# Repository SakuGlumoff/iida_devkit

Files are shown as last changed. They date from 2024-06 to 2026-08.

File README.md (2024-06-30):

# Iida devkit

PCB design exercise

## Hardware

Hardware design related files can be found in the `hardware` directory.
To get started with hardware development, take a look at the _README_ file therein.

The harware was designed with [KiCad EDA](https://www.kicad.org/) and manufactured with [Aisler](https://aisler.net/).

## Firmware

Firmware source files can be found in the `firmware` directory.
To get started with firmware development, take a look at the _README_ file therein.

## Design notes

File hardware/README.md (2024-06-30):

# Hardware

Hardware for Iida devkit.

## Requirements

| Tool  | Version |
|---|---|
| KiCad | >= 8 |
| Git | >= 2.34 |

## How to get started

Install the required version of _KiCad_ from https://www.kicad.org/download/.
Install the required version of _Git_ from https://git-scm.com/downloads.
Download the symbol and part libraries used in this project by running `git submodule update --init --recursive`.
You can now open the project file `iida_devkit.kicad_pro` with _KiCad_.

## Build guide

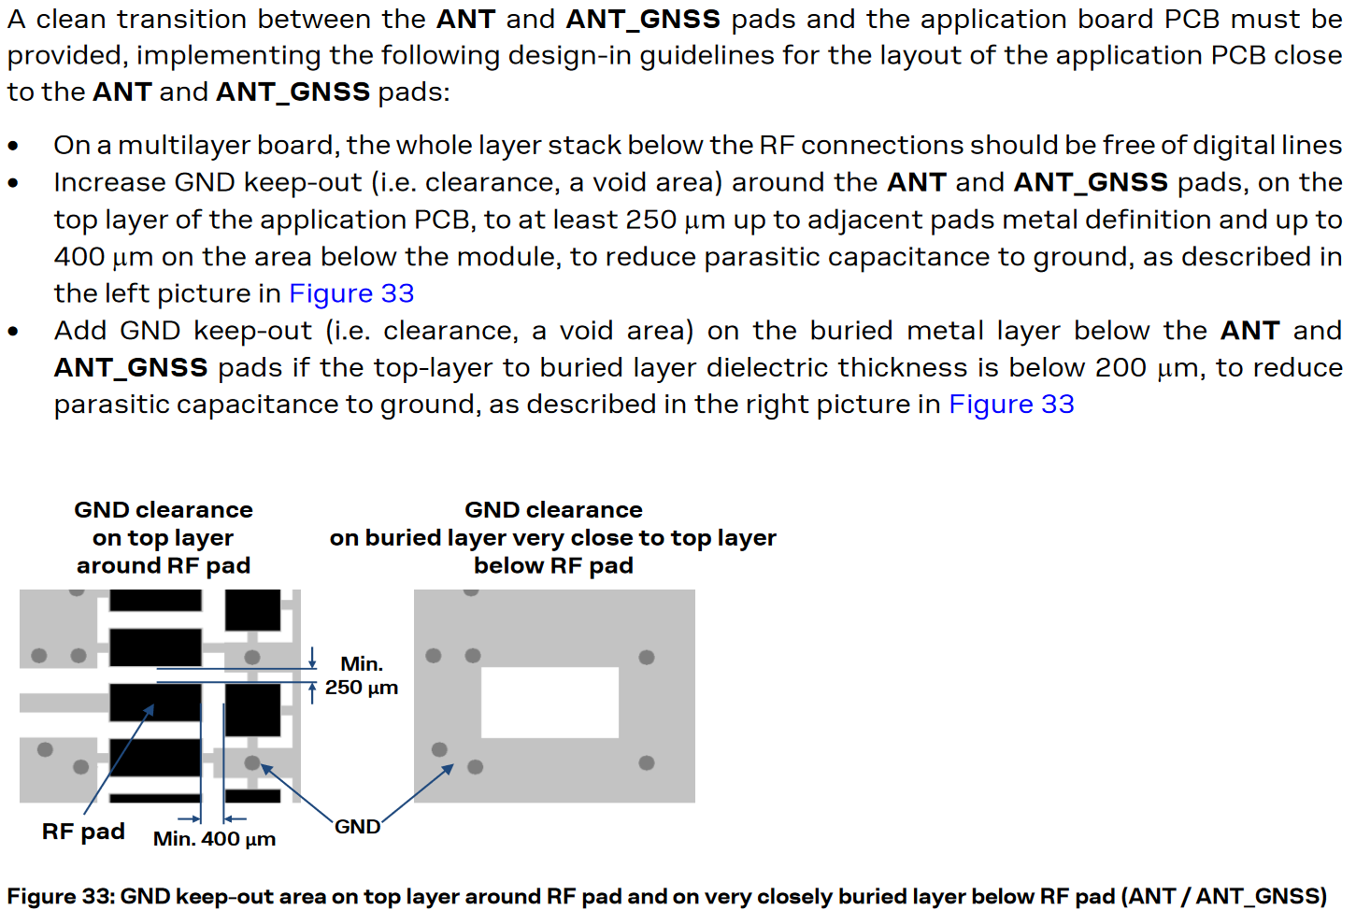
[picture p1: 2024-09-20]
hardware/img/sara-r5-sysintegrmanual-ant-pin.png

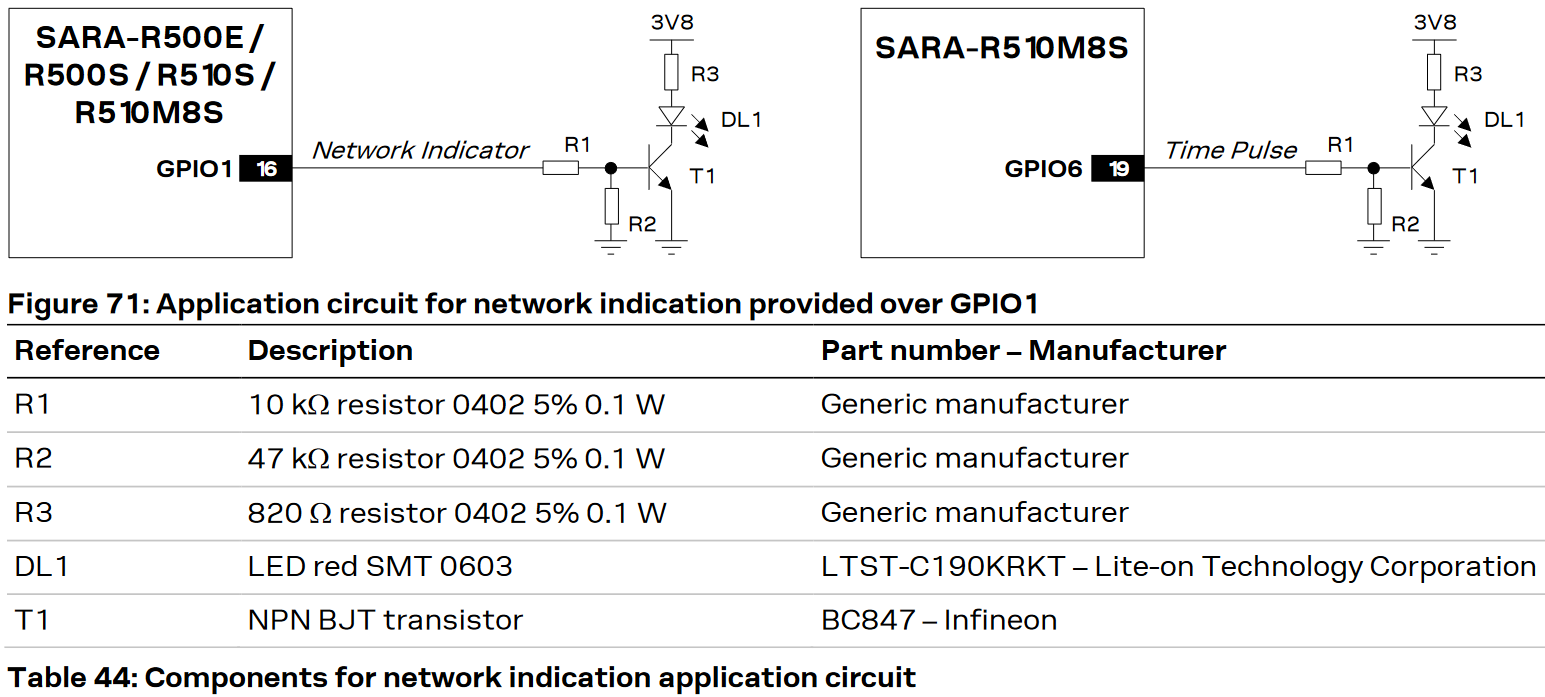
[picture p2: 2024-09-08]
hardware/img/sara-r5-sysintegrmanual-net-ind.png

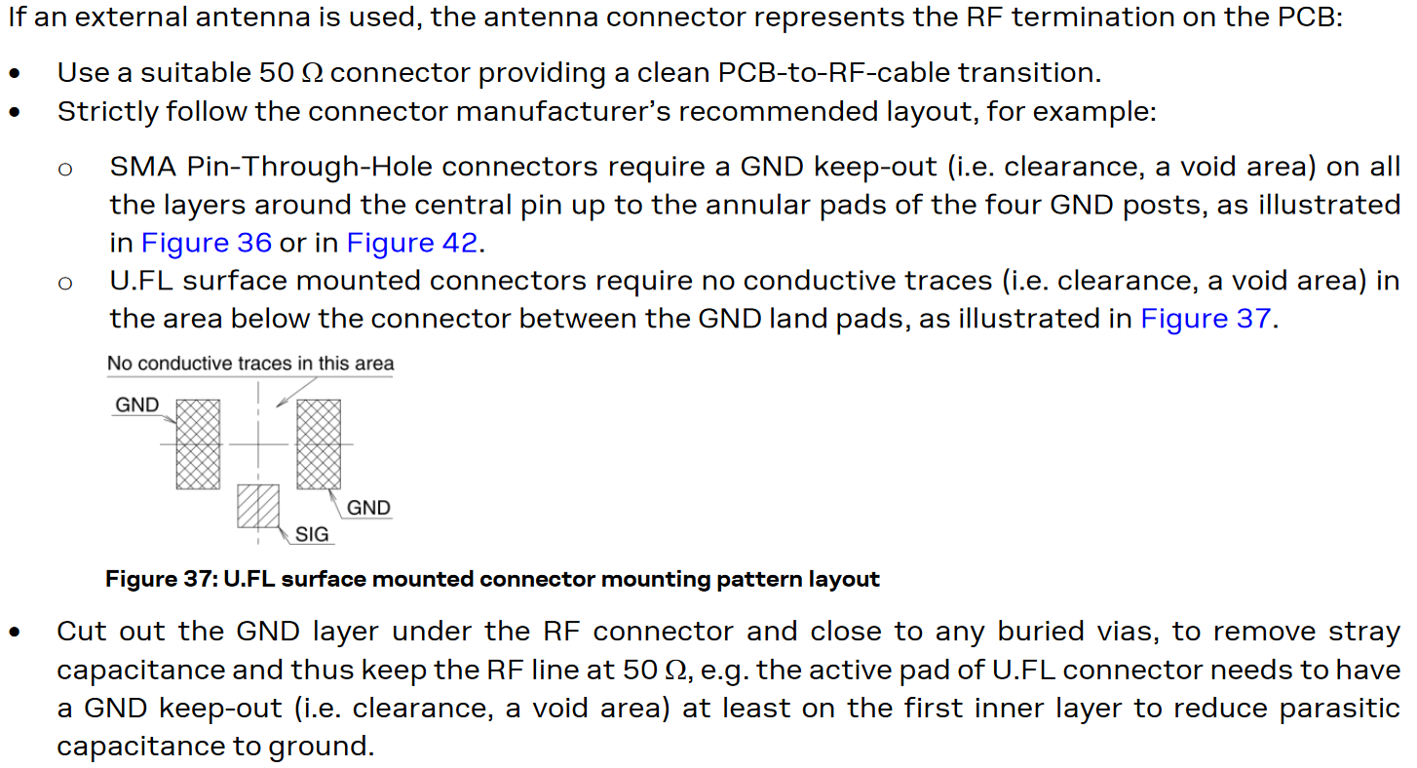
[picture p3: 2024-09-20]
hardware/img/sara-r5-sysintegrmanual-ant-ext.png

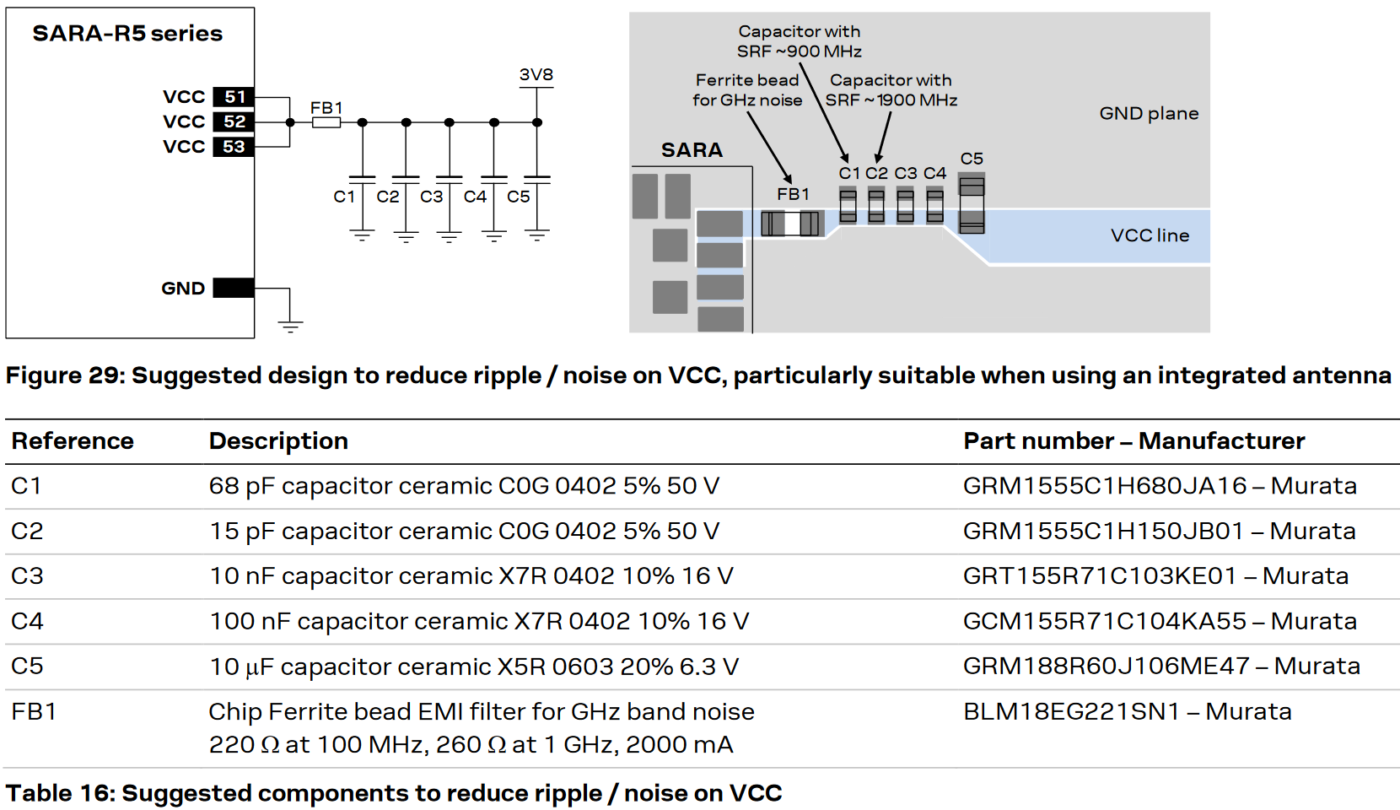
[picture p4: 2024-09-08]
hardware/img/sara-r5-sysintegrmanual-vcc.png

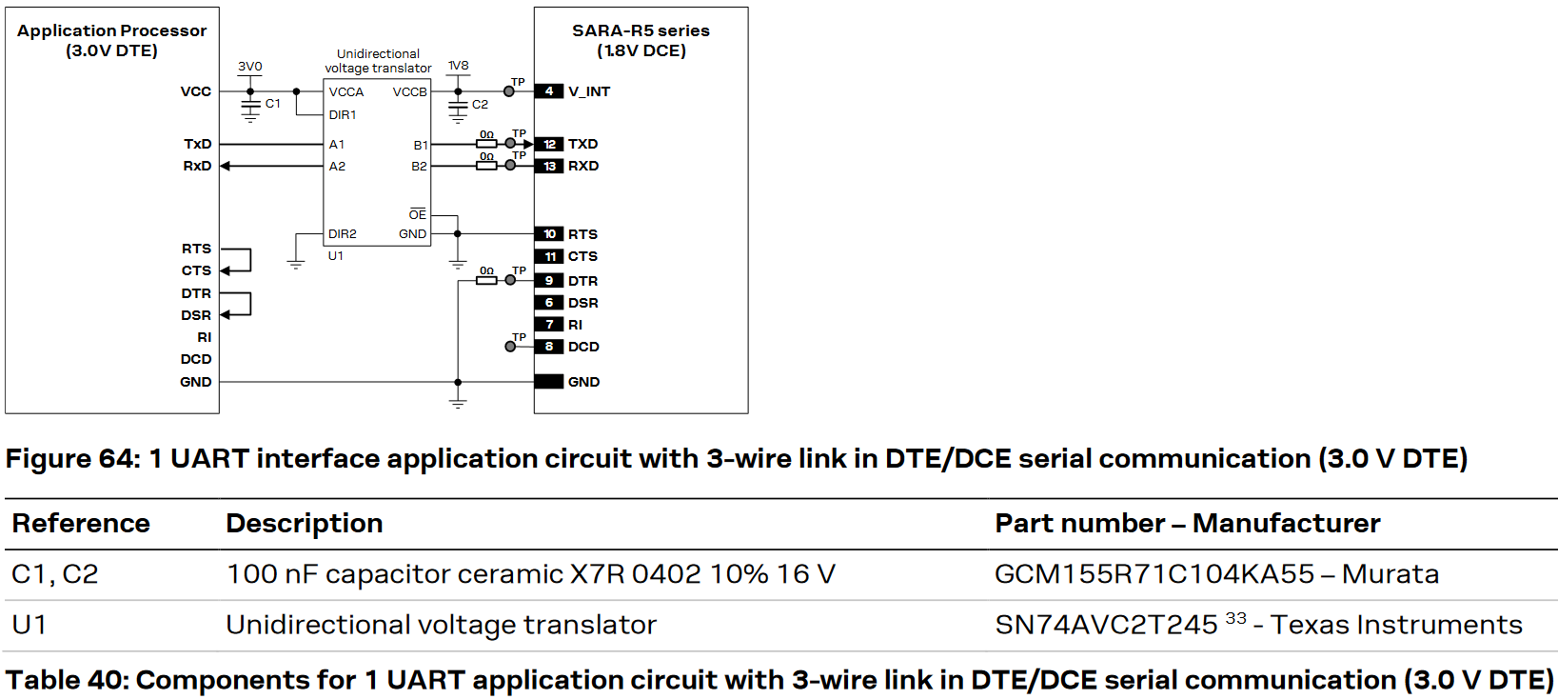
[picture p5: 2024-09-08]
hardware/img/sara-r5-sysintegrmanual-uart.png

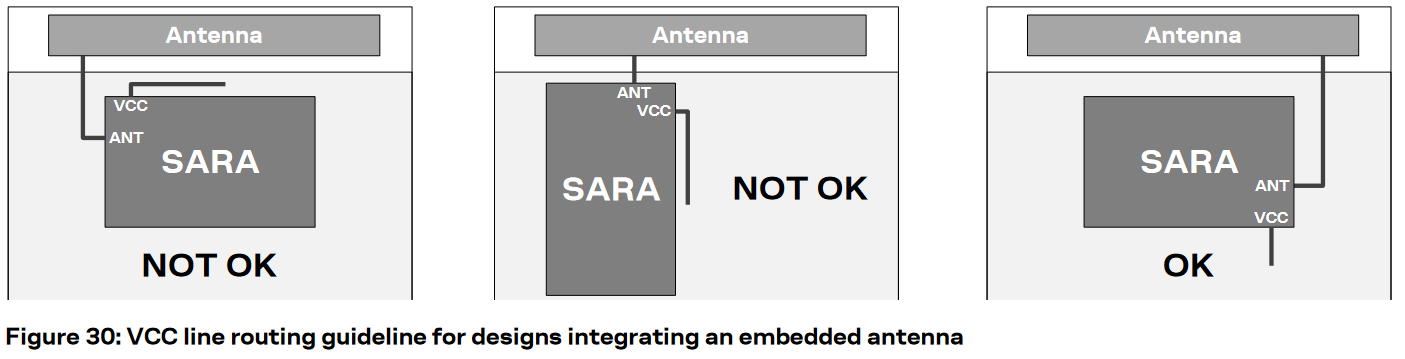
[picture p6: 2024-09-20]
hardware/img/sara-r5-sysintegrmanual-vcc-ant.png

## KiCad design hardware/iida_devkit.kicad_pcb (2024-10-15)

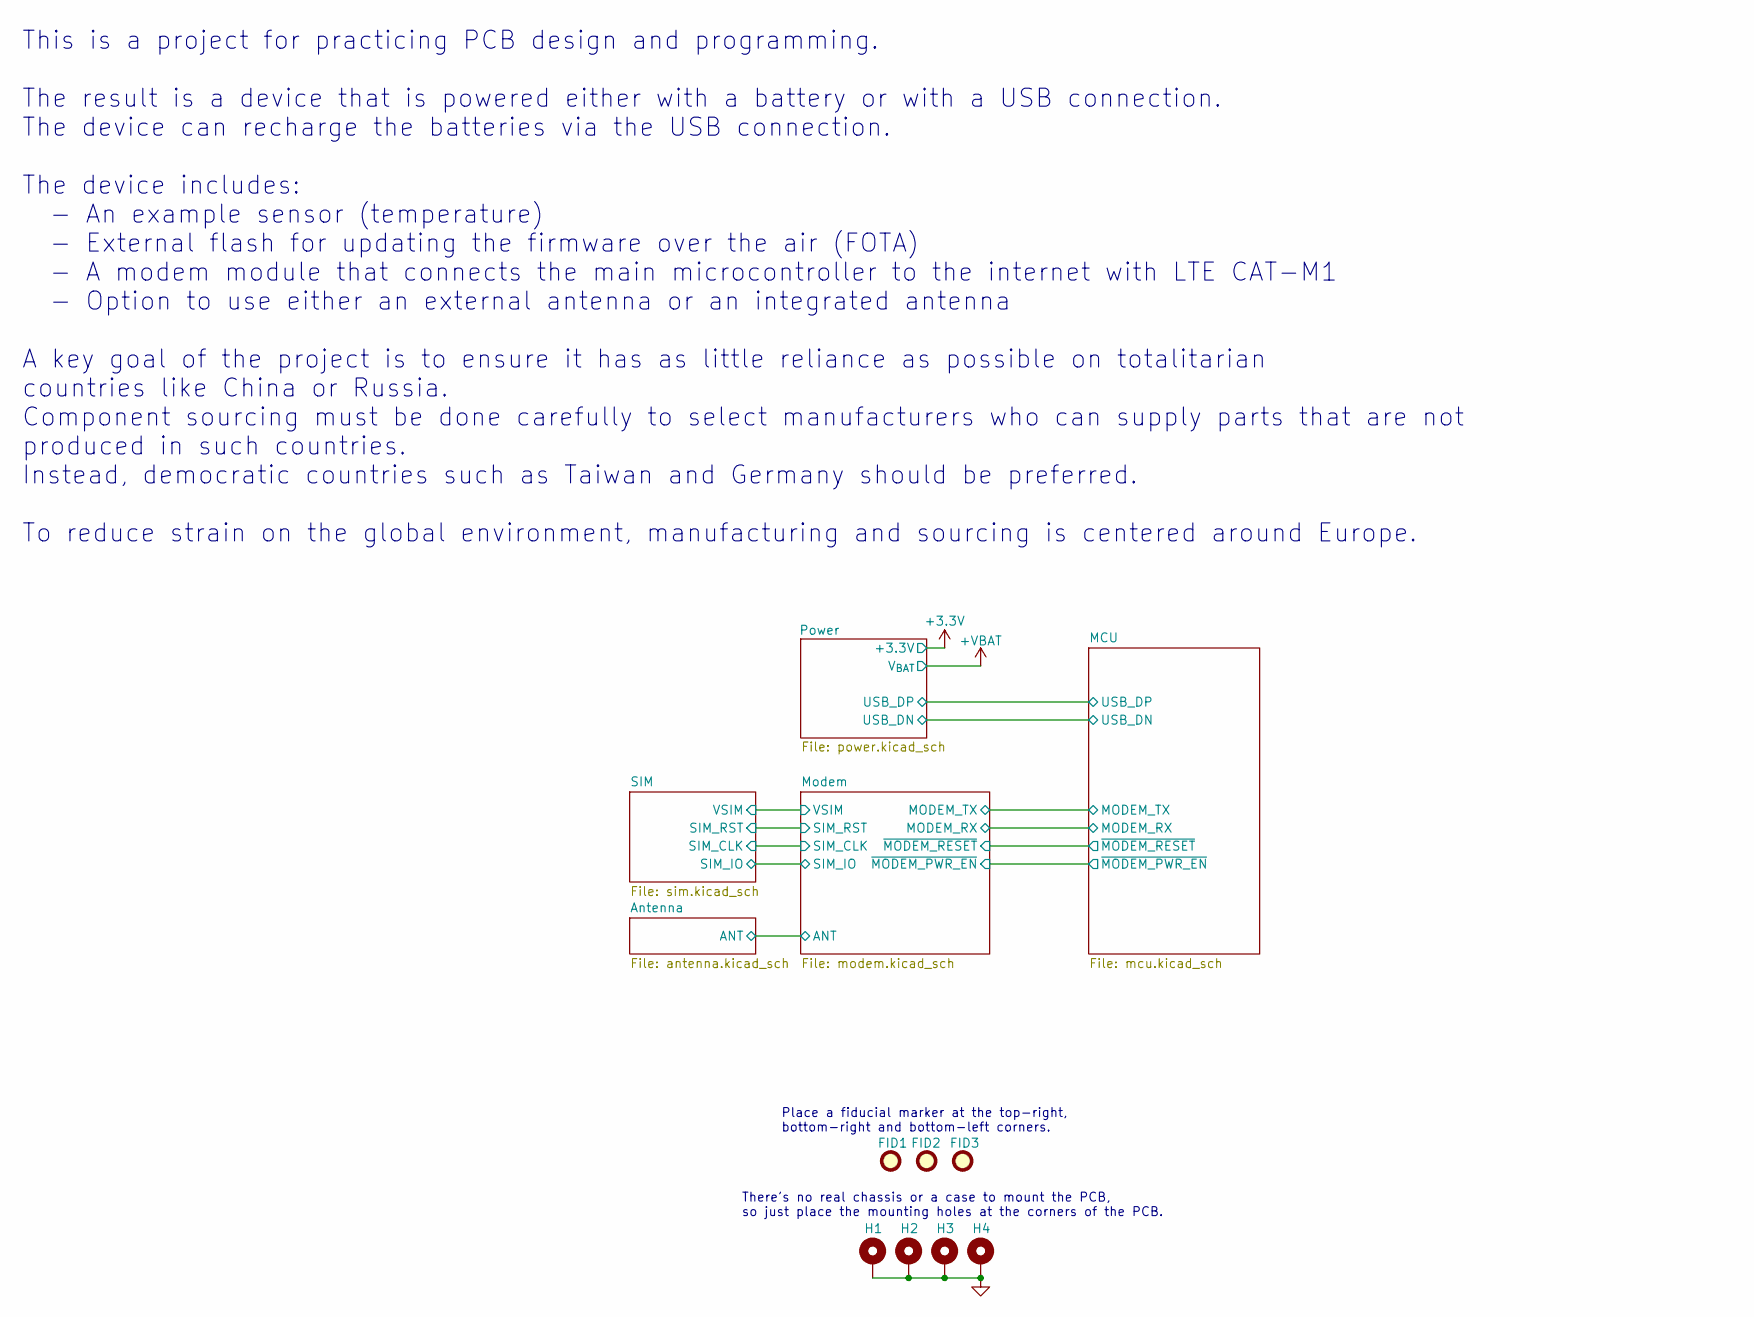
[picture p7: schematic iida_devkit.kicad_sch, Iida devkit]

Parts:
FID1, FID2, FID3: Fiducial; Fiducial_1mm_Mask2mm
H1, H2, H3, H4: MountingHole_Pad; MountingHole_2.2mm_M2_Pad_Via

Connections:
GND: H1.1, H2.1, H3.1, H4.1; also elsewhere on the board

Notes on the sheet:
There's no real chassis or a case to mount the PCB, so just place the mounting holes at the corners of the PCB.
Place a fiducial marker at the top-right, bottom-right and bottom-left corners.
This is a project for practicing PCB design and programming. The result is a device that is powered either with a battery or with a USB connection. The device can recharge the batteries via the USB connection. The device includes: - An example sensor (temperature) - External flash for updating the 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

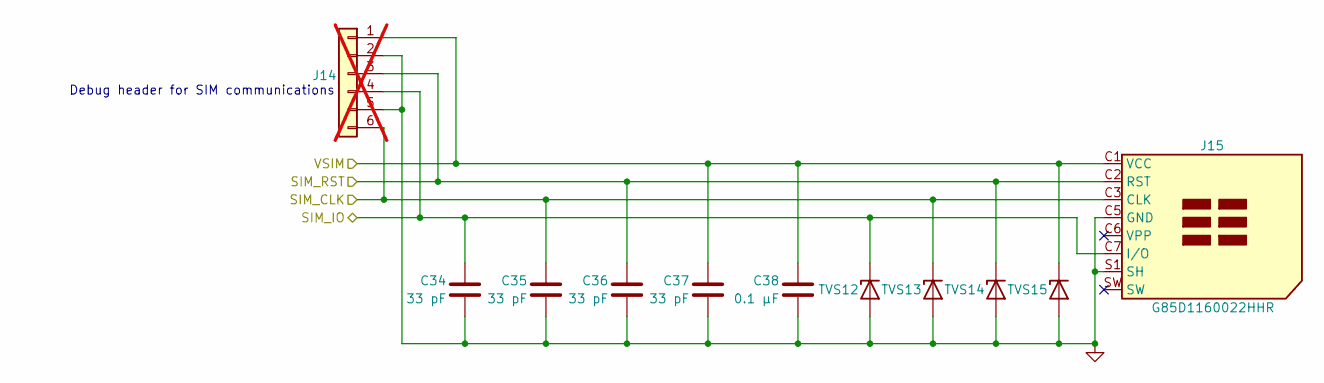
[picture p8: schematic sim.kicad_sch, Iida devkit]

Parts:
C34, C35, C36, C37: 33 pF; C_0603_1608Metric_Pad1.08x0.95mm_HandSolder; Manufacturer Part Number 885012006005; Digi-Key Part Number 732-7749-1-ND
C38: 0.1 µF; C_0603_1608Metric_Pad1.08x0.95mm_HandSolder; Manufacturer Part Number 885012206071; Digi-Key Part Number 732-7989-1-ND
J14: PRPC006SAAN-RC; PinHeader_1x06_P2.54mm_Vertical; Manufacturer Part Number PRPC006SAAN-RC; Digi-Key Part Number S1011EC-06-ND; not fitted
J15: G85D1160022HHR; AMPHENOL_G85D1160022HHR; Manufacturer Part Number G85D1160022HHR; Digi-Key Part Number 664-G85D1160022HHRCT-ND
TVS12, TVS13, TVS14, TVS15: CPDUC5V0USP-HF; D_0603_1608Metric_Pad1.05x0.95mm_HandSolder; Manufacturer Part Number CPDUC5V0USP-HF; Digi-Key Part Number 641-1765-1-ND

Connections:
/Modem/SIM_CLK: C35.1, J14.6, J15.C3 (CLK), TVS13.1 (K); also elsewhere on the board
/Modem/SIM_IO: C34.1, J14.4, J15.C7 (I/O), TVS12.1 (K); also elsewhere on the board
/Modem/SIM_RST: C36.1, J14.3, J15.C2 (RST), TVS14.1 (K); also elsewhere on the board
/Modem/VSIM: C37.1, C38.1, J14.1, J15.C1 (VCC), TVS15.1 (K); also elsewhere on the board
GND: C34.2, C35.2, C36.2, C37.2, C38.2, J14.2, J14.5, J15.C5 (GND), J15.S1 (SH), J15.S2 (SH), J15.S3 (SH), TVS12.2 (A), TVS13.2 (A), TVS14.2 (A), TVS15.2 (A); also elsewhere on the board

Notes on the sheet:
Debug header for SIM communications

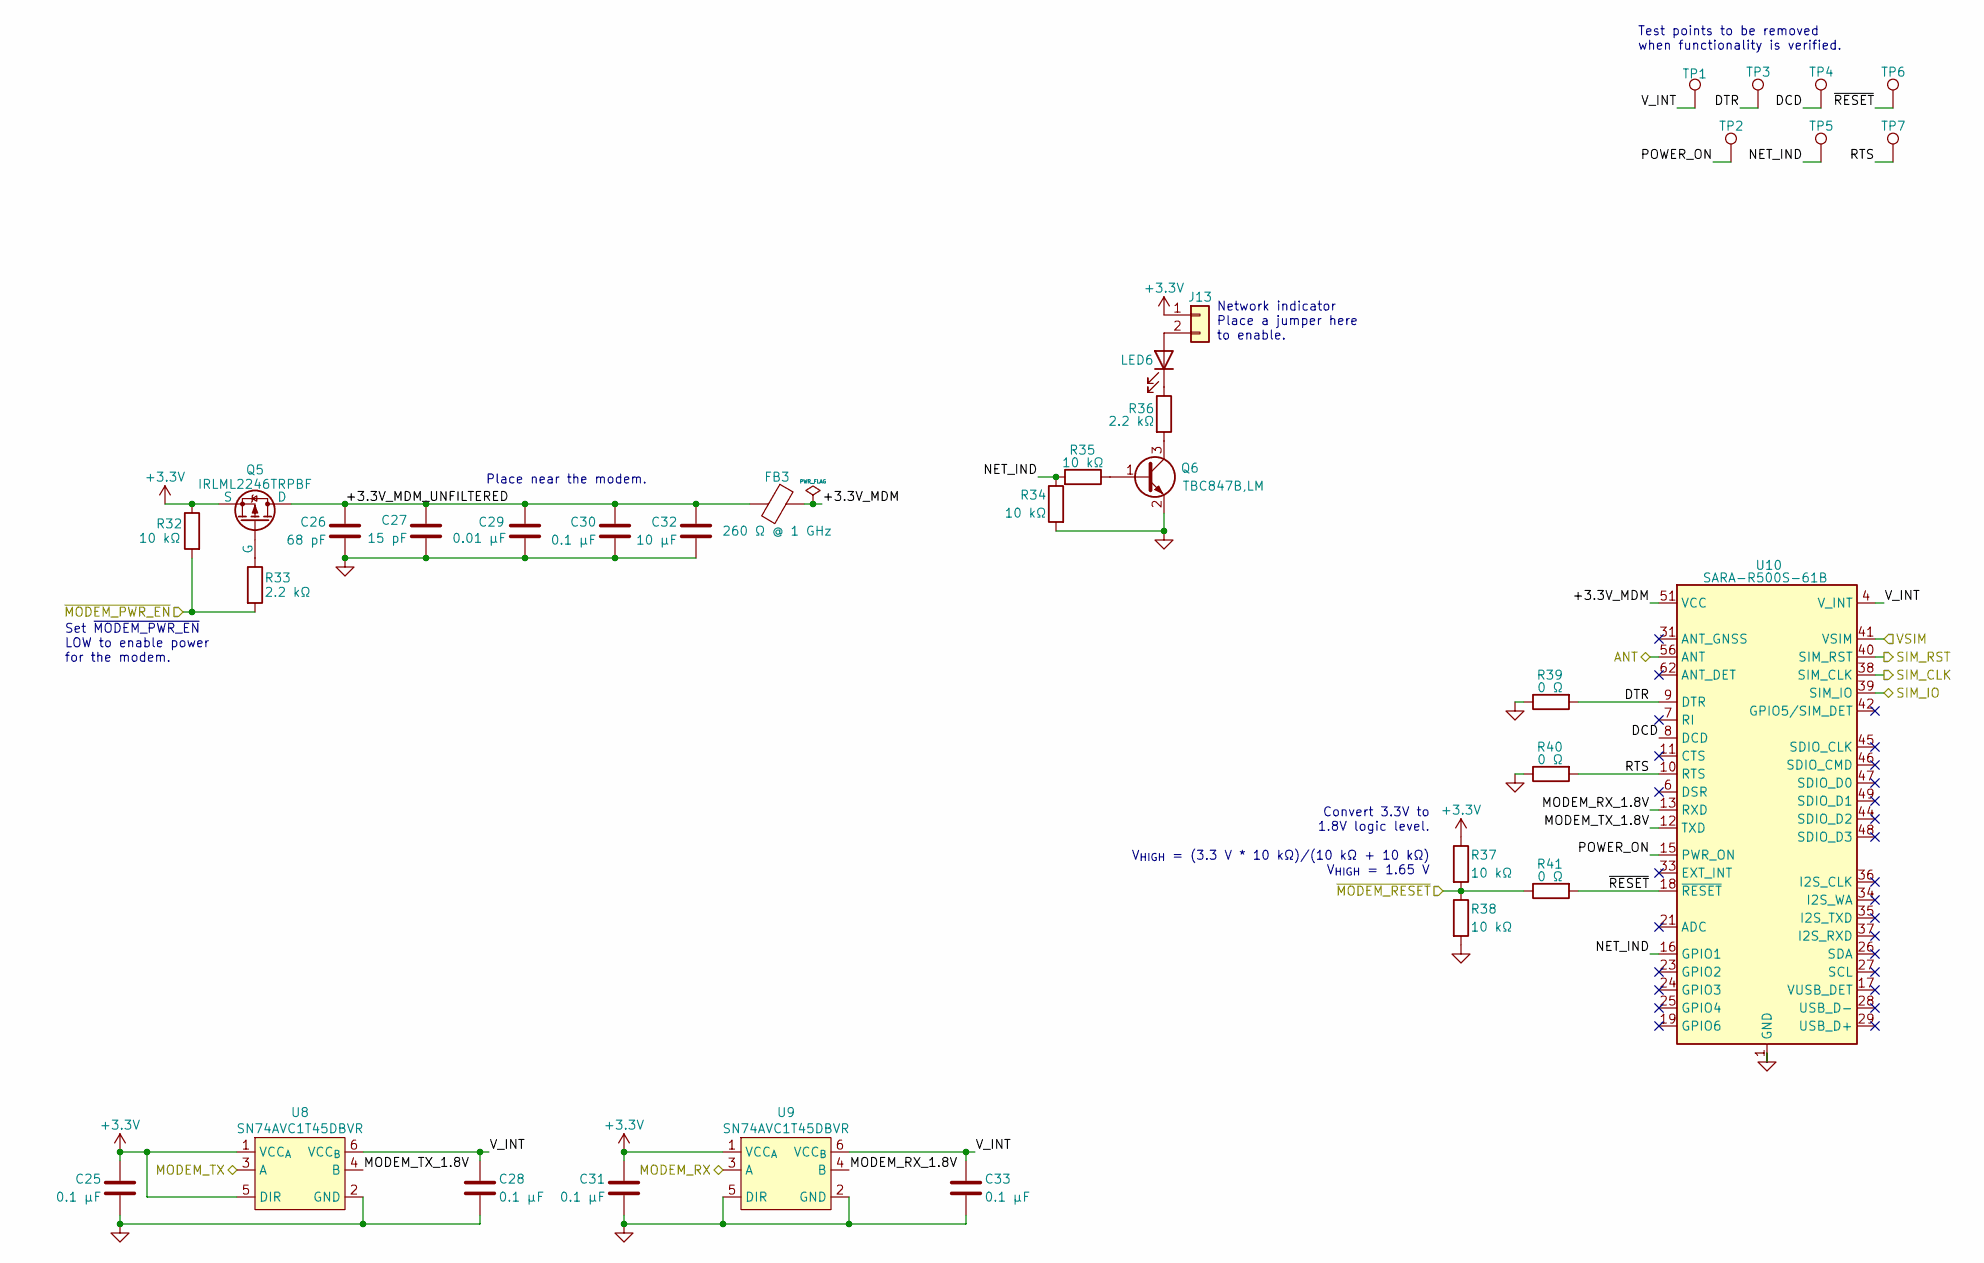
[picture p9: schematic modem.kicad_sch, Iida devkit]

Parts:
C25, C28, C30, C31, C33: 0.1 µF; C_0603_1608Metric_Pad1.08x0.95mm_HandSolder; Manufacturer Part Number 885012206071; Digi-Key Part Number 732-7989-1-ND
C26: 68 pF; C_0603_1608Metric_Pad1.08x0.95mm_HandSolder; Manufacturer Part Number 885012006037; Digi-Key Part Number 732-7779-1-ND
C27: 15 pF; C_0603_1608Metric_Pad1.08x0.95mm_HandSolder; Manufacturer Part Number 885012006003; Digi-Key Part Number 732-7747-1-ND
C29: 0.01 µF; C_0603_1608Metric_Pad1.08x0.95mm_HandSolder; Manufacturer Part Number 885012206089; Digi-Key Part Number 732-8007-1-ND
C32: 10 µF; C_0603_1608Metric_Pad1.08x0.95mm_HandSolder; Manufacturer Part Number 885012106006; Digi-Key Part Number 732-7903-1-ND
FB3: 260 Ω @ 1 GHz; R_0603_1608Metric_Pad0.98x0.95mm_HandSolder; Manufacturer Part Number BLM18EG221SN1D; Digi-Key Part Number 490-3992-1-ND
J13: PRPC001DAAN-RC; PinHeader_1x02_P2.54mm_Vertical; Manufacturer Part Number PRPC001DAAN-RC; Digi-Key Part Number S2011EC-01-ND
LED6: 150141YS73100; LED_PLCC_2835_Handsoldering; Manufacturer Part Number 150141YS73100; Digi-Key Part Number 732-5004-1-ND
Q5: IRLML2246TRPBF; SC-59_Handsoldering; Manufacturer Part Number IRLML2246TRPBF; Digi-Key Part Number IRLML2246TRPBFCT-ND
Q6: TBC847B,LM; SC-59_Handsoldering; Manufacturer Part Number TBC847B,LM; Digi-Key Part Number TBC847BLMCT-ND
R32, R34, R35, R37, R38: 10 kΩ; R_0603_1608Metric_Pad0.98x0.95mm_HandSolder; Manufacturer Part Number 560112116005; Digi-Key Part Number 732-560112116005CT-ND
R33, R36: 2.2 kΩ; R_0603_1608Metric_Pad0.98x0.95mm_HandSolder; Manufacturer Part Number 560112116098; Digi-Key Part Number 732-560112116098CT-ND
R39, R40, R41: 0 Ω; R_0805_2012Metric_Pad1.20x1.40mm_HandSolder; Manufacturer Part Number 560112120002; Digi-Key Part Number 732-560112120002CT-ND
TP1, TP2, TP3, TP4, TP5, TP6, TP7: TestPoint; TestPoint_Pad_D1.5mm
U8, U9: SN74AVC1T45DBVR; SOT-23-6_Handsoldering; Manufacturer Part Number SN74AVC1T45DBVR; Digi-Key Part Number 296-19094-1-ND
U10: SARA-R500S-61B; ublox_SARA_LGA-96; Manufacturer Part Number SARA-R500S-61B; Digi-Key Part Number 672-SARA-R500S-61BCT-ND

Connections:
+3.3V: C25.1, C31.1, J13.1, Q5.3 (S), R32.1, R37.1, U8.1 (VCC_{A}), U8.5 (DIR), U9.1 (VCC_{A}); also elsewhere on the board
/Antenna/ANT: U10.56 (ANT); also elsewhere on the board
/MCU/MODEM_RX: U9.3 (A); also elsewhere on the board
/MCU/MODEM_TX: U8.3 (A); also elsewhere on the board
/MCU/~MODEM_PWR_EN: R32.2, R33.2; also elsewhere on the board
/MCU/~MODEM_RESET: R37.2, R38.1, R41.1; also elsewhere on the board
/Modem/+3.3V_MDM: FB3.1, U10.51 (VCC), U10.52 (VCC), U10.53 (VCC)
/Modem/+3.3V_MDM_UNFILTERED: C26.1, C27.1, C29.1, C30.1, C32.1, FB3.2, Q5.1 (D)
/Modem/DCD: TP4.1, U10.8 (DCD)
/Modem/DTR: R39.2, TP3.1, U10.9 (DTR)
/Modem/MODEM_RX_1.8V: U9.4 (B), U10.13 (RXD)
/Modem/MODEM_TX_1.8V: U8.4 (B), U10.12 (TXD)
/Modem/NET_IND: R34.1, R35.2, TP5.1, U10.16 (GPIO1)
/Modem/POWER_ON: TP2.1, U10.15 (PWR_ON)
/Modem/RTS: R40.2, TP7.1, U10.10 (RTS)
/Modem/SIM_CLK: U10.38 (SIM_CLK); also elsewhere on the board
/Modem/SIM_IO: U10.39 (SIM_IO); also elsewhere on the board
/Modem/SIM_RST: U10.40 (SIM_RST); also elsewhere on the board
/Modem/VSIM: U10.41 (VSIM); also elsewhere on the board
/Modem/V_INT: C28.1, C33.1, TP1.1, U8.6 (VCC_{B}), U9.6 (VCC_{B}), U10.4 (V_INT)
/Modem/~RESET: R41.2, TP6.1, U10.18 (~RESET)
GND: C25.2, C26.2, C27.2, C28.2, C29.2, C30.2, C31.2, C32.2, C33.2, Q6.2 (E), R34.2, R38.2, R39.1, R40.1, U8.2 (GND), U9.2 (GND), U9.5 (DIR), U10.1 (GND), U10.3 (GND), U10.5 (GND), U10.14 (GND), U10.20 (GND), U10.22 (GND), U10.30 (GND), U10.32 (GND), U10.43 (GND), U10.50 (GND), U10.54 (GND), U10.55 (GND), U10.57 (GND), U10.58 (GND), U10.59 (GND), U10.60 (GND), U10.61 (GND), U10.63 (GND), U10.64 (GND), U10.65 (GND), U10.66 (GND), U10.67 (GND), U10.68 (GND), U10.69 (GND), U10.70 (GND), U10.71 (GND), U10.72 (GND), U10.73 (GND), U10.74 (GND), U10.75 (GND), U10.76 (GND), U10.77 (GND), U10.78 (GND), U10.79 (GND), U10.80 (GND), U10.81 (GND), U10.82 (GND), U10.83 (GND), U10.84 (GND), U10.85 (GND), U10.86 (GND), U10.87 (GND), U10.88 (GND), U10.89 (GND), U10.90 (GND), U10.91 (GND), U10.92 (GND), U10.93 (GND), U10.94 (GND), U10.95 (GND), U10.96 (GND); also elsewhere on the board
unnamed: J13.2, LED6.2 (A)
unnamed: LED6.1 (K), R36.1
unnamed: Q5.2 (G), R33.1
unnamed: Q6.1 (B), R35.1
unnamed: Q6.3 (C), R36.2

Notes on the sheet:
Convert 3.3V to 1.8V logic level. V_{HIGH} = (3.3 V * 10 kΩ)/(10 kΩ + 10 kΩ) V_{HIGH} = 1.65 V
Place near the modem.
Set ~{MODEM_PWR_EN} LOW to enable power for the modem.
Test points to be removed when functionality is verified.
Network indicator Place a jumper here to enable.

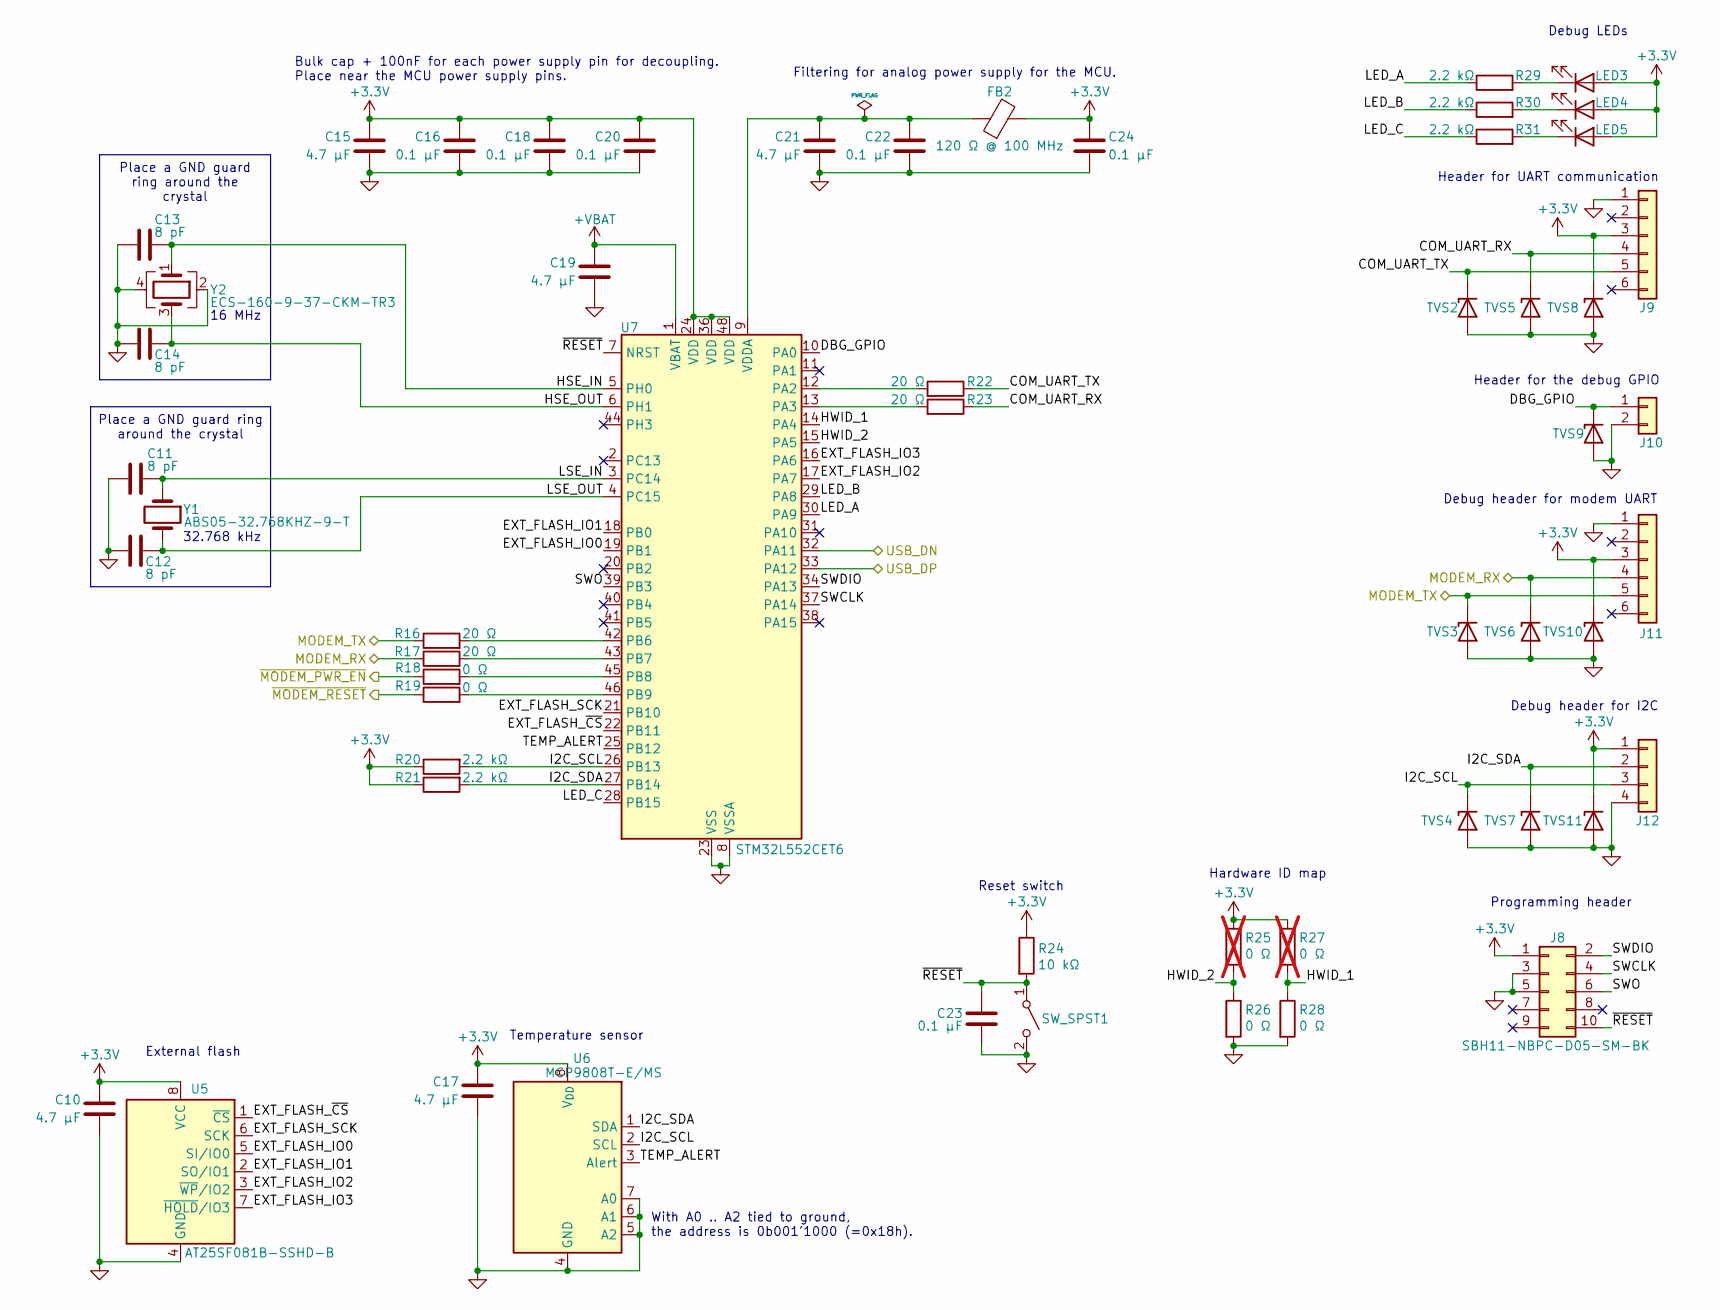
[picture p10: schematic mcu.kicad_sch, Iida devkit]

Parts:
C10, C15, C17, C19, C21: 4.7 µF; C_0805_2012Metric_Pad1.18x1.45mm_HandSolder; Manufacturer Part Number 885012107013; Digi-Key Part Number 732-7623-1-ND
C11, C12, C13, C14: 8 pF; C_0603_1608Metric_Pad1.08x0.95mm_HandSolder; Manufacturer Part Number 885012006093; Digi-Key Part Number 732-12050-1-ND
C16, C18, C20, C22, C23, C24: 0.1 µF; C_0603_1608Metric_Pad1.08x0.95mm_HandSolder; Manufacturer Part Number 885012206071; Digi-Key Part Number 732-7989-1-ND
FB2: 120 Ω @ 100 MHz; R_0603_1608Metric_Pad0.98x0.95mm_HandSolder; Manufacturer Part Number BLM18KG121TN1D; Digi-Key Part Number 490-5254-1-ND
J8: SBH11-NBPC-D05-SM-BK; IDC-Header_2x05_P2.54mm_Vertical_SMD; Manufacturer Part Number SBH11-NBPC-D05-SM-BK; Digi-Key Part Number S9185-ND
J9, J11: PRPC006SAAN-RC; PinHeader_1x06_P2.54mm_Vertical; Manufacturer Part Number PRPC006SAAN-RC; Digi-Key Part Number S1011EC-06-ND
J10: PRPC001DAAN-RC; PinHeader_1x02_P2.54mm_Vertical; Manufacturer Part Number PRPC001DAAN-RC; Digi-Key Part Number S2011EC-01-ND
J12: PRPC004SAAN-RC; PinHeader_1x04_P2.54mm_Vertical; Manufacturer Part Number PRPC004SAAN-RC; Digi-Key Part Number S1011EC-04-ND
LED3, LED4, LED5: 150141YS73100; LED_PLCC_2835_Handsoldering; Manufacturer Part Number 150141YS73100; Digi-Key Part Number 732-5004-1-ND
R16, R17, R22, R23: 20 Ω; R_0603_1608Metric_Pad0.98x0.95mm_HandSolder; Manufacturer Part Number 560112116125; Digi-Key Part Number 732-560112116125CT-ND
R18, R19, R26, R28: 0 Ω; R_0805_2012Metric_Pad1.20x1.40mm_HandSolder; Manufacturer Part Number 560112120002; Digi-Key Part Number 732-560112120002CT-ND
R20, R21, R29, R30, R31: 2.2 kΩ; R_0603_1608Metric_Pad0.98x0.95mm_HandSolder; Manufacturer Part Number 560112116098; Digi-Key Part Number 732-560112116098CT-ND
R24: 10 kΩ; R_0603_1608Metric_Pad0.98x0.95mm_HandSolder; Manufacturer Part Number 560112116005; Digi-Key Part Number 732-560112116005CT-ND
R25, R27: 0 Ω; R_0805_2012Metric_Pad1.20x1.40mm_HandSolder; Manufacturer Part Number 560112120002; Digi-Key Part Number 732-560112120002CT-ND; not fitted
SW_SPST1: 430182050816; SW_SPST_PTS645; Manufacturer Part Number 430182050816; Digi-Key Part Number 732-7005-1-ND
TVS2, TVS3, TVS4, TVS5, TVS6, TVS7, TVS8, TVS9, TVS10, TVS11: CPDUC5V0USP-HF; D_0603_1608Metric_Pad1.05x0.95mm_HandSolder; Manufacturer Part Number CPDUC5V0USP-HF; Digi-Key Part Number 641-1765-1-ND
U5: AT25SF081B-SSHD-B; SOIC-8_3.9x4.9mm_P1.27mm; Manufacturer Part Number AT25SF081B-SSHD-B; Digi-Key Part Number 1265-AT25SF081B-SSHD-B-ND
U6: MCP9808T-E/MS; MSOP-8_3x3mm_P0.65mm; Manufacturer Part Number MCP9808T-E/MS; Digi-Key Part Number MCP9808T-E/MSCT-ND
U7: STM32L552CET6; LQFP-48_7x7mm_P0.5mm; Manufacturer Part Number STM32L552CET6; Digi-Key Part Number 497-STM32L552CET6-ND
Y1: ABS05-32.768KHZ-9-T; Crystal_SMD_MicroCrystal_CM9V-T1A-2Pin_1.6x1.0mm_HandSolder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; Manufacturer Part Number ABS05-32.768KHZ-9-T; Digi-Key Part Number 535-ABS05-32.768KHZ-9-TCT-ND
Y2: ECS-160-9-37-CKM-TR3; Crystal_SMD_3225-4Pin_3.2x2.5mm_HandSoldering; Manufacturer Part Number ECS-160-9-33B-CKM-TR3; Digi-Key Part Number 50-ECS-160-9-33B-CKM-TR3CT-ND

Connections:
+3.3V: C10.1, C15.1, C16.1, C17.1, C18.1, C20.1, C24.1, FB2.2, J8.1, J9.3, J11.3, J12.1, LED3.2 (A), LED4.2 (A), LED5.2 (A), R20.1, R21.1, R24.1, R25.1, R27.1, TVS8.1 (K), TVS10.1 (K), TVS11.1 (K), U5.8 (VCC), U6.8 (V_{DD}), U7.24 (VDD), U7.36 (VDD), U7.48 (VDD); also elsewhere on the board
+VBAT: C19.1, U7.1 (VBAT); also elsewhere on the board
/MCU/COM_UART_RX: J9.4, R23.1, TVS5.1 (K)
/MCU/COM_UART_TX: J9.5, R22.1, TVS2.1 (K)
/MCU/DBG_GPIO: J10.1, TVS9.1 (K), U7.10 (PA0)
/MCU/EXT_FLASH_IO0: U5.5 (SI/IO0), U7.19 (PB1)
/MCU/EXT_FLASH_IO1: U5.2 (SO/IO1), U7.18 (PB0)
/MCU/EXT_FLASH_IO2: U5.3 (~WP/IO2), U7.17 (PA7)
/MCU/EXT_FLASH_IO3: U5.7 (~HOLD/IO3), U7.16 (PA6)
/MCU/EXT_FLASH_SCK: U5.6 (SCK), U7.21 (PB10)
/MCU/EXT_FLASH_~CS: U5.1 (~CS), U7.22 (PB11)
/MCU/HSE_IN: C13.1, U7.5 (PH0), Y2.1
/MCU/HSE_OUT: C14.1, U7.6 (PH1), Y2.3
/MCU/HWID_1: R27.2, R28.1, U7.14 (PA4)
/MCU/HWID_2: R25.2, R26.1, U7.15 (PA5)
/MCU/I2C_SCL: J12.3, R20.2, TVS4.1 (K), U6.2 (SCL), U7.26 (PB13)
/MCU/I2C_SDA: J12.2, R21.2, TVS7.1 (K), U6.1 (SDA), U7.27 (PB14)
/MCU/LED_A: R29.1, U7.30 (PA9)
/MCU/LED_B: R30.1, U7.29 (PA8)
/MCU/LED_C: R31.1, U7.28 (PB15)
/MCU/LSE_IN: C11.1, U7.3 (PC14), Y1.1
/MCU/LSE_OUT: C12.1, U7.4 (PC15), Y1.2
/MCU/MODEM_RX: J11.4, R17.1, TVS6.1 (K); also elsewhere on the board
/MCU/MODEM_TX: J11.5, R16.1, TVS3.1 (K); also elsewhere on the board
/MCU/SWCLK: J8.4, U7.37 (PA14)
/MCU/SWDIO: J8.2, U7.34 (PA13)
/MCU/SWO: J8.6, U7.39 (PB3)
/MCU/TEMP_ALERT: U6.3 (Alert), U7.25 (PB12)
/MCU/USB_DN: U7.32 (PA11); also elsewhere on the board
/MCU/USB_DP: U7.33 (PA12); also elsewhere on the board
/MCU/~MODEM_PWR_EN: R18.1; also elsewhere on the board
/MCU/~MODEM_RESET: R19.1; also elsewhere on the board
/MCU/~RESET: C23.2, J8.10, R24.2, SW_SPST1.1 (A), U7.7 (NRST)
GND: C10.2, C11.2, C12.2, C13.2, C14.2, C15.2, C16.2, C17.2, C18.2, C19.2, C20.2, C21.2, C22.2, C23.1, C24.2, J8.3, J8.5, J9.1, J10.2, J11.1, J12.4, R26.2, R28.2, SW_SPST1.2 (B), TVS2.2 (A), TVS3.2 (A), TVS4.2 (A), TVS5.2 (A), TVS6.2 (A), TVS7.2 (A), TVS8.2 (A), TVS9.2 (A), TVS10.2 (A), TVS11.2 (A), U5.4 (GND), U6.4 (GND), U6.5 (A2), U6.6 (A1), U6.7 (A0), U7.8 (VSSA), U7.23 (VSS), U7.35 (VSS), U7.47 (VSS), Y2.2, Y2.4; also elsewhere on the board
unnamed: LED3.1 (K), R29.2
unnamed: LED4.1 (K), R30.2
unnamed: LED5.1 (K), R31.2
unnamed: R22.2, U7.12 (PA2)
unnamed: R23.2, U7.13 (PA3)
unnamed: R16.2, U7.42 (PB6)
unnamed: R17.2, U7.43 (PB7)
unnamed: R18.2, U7.45 (PB8)
unnamed: R19.2, U7.46 (PB9)
unnamed: C21.1, C22.1, FB2.1, U7.9 (VDDA)

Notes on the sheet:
Place a GND guard ring around the crystal
Programming header
Reset switch
External flash
Header for the debug GPIO
Temperature sensor
Debug header for modem UART
Hardware ID map
Filtering for analog power supply for the MCU.
Debug LEDs
Debug header for I2C
Header for UART communication
16 MHz
32.768 kHz
With A0 .. A2 tied to ground, the address is 0b001'1000 (=0x18h).
Bulk cap + 100nF for each power supply pin for decoupling. Place near the MCU power supply pins.

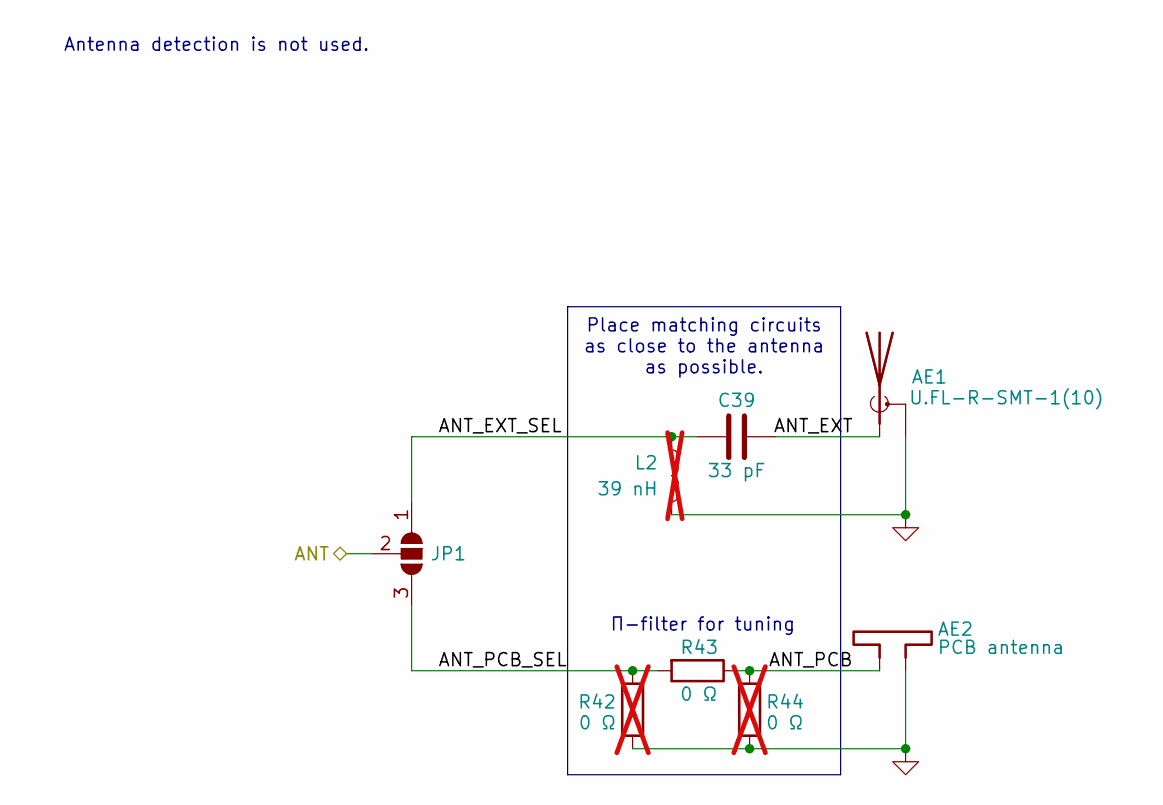
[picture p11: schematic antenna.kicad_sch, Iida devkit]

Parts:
AE1: U.FL-R-SMT-1(10); U.FL_Hirose_U.FL-R-SMT-1_Vertical; Manufacturer Part Number U.FL-R-SMT-1(10); Digi-Key Part Number H11891CT-ND
AE2: PCB antenna; 800MHz_antenna
C39: 33 pF; C_0603_1608Metric_Pad1.08x0.95mm_HandSolder; Manufacturer Part Number 885012006005; Digi-Key Part Number 732-7749-1-ND
JP1: SolderJumper_3_Open; 0Ohm_choice_90_degree_0402
L2: 39 nH; L_0603_1608Metric_Pad1.05x0.95mm_HandSolder; Manufacturer Part Number LQG15HS39NJ02D; Digi-Key Part Number 490-2630-1-ND; not fitted
R42, R44: 0 Ω; R_0805_2012Metric_Pad1.20x1.40mm_HandSolder; Manufacturer Part Number 560112120002; Digi-Key Part Number 732-560112120002CT-ND; not fitted
R43: 0 Ω; R_0805_2012Metric_Pad1.20x1.40mm_HandSolder; Manufacturer Part Number 560112120002; Digi-Key Part Number 732-560112120002CT-ND

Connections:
/Antenna/ANT: JP1.2 (C); also elsewhere on the board
/Antenna/ANT_EXT: AE1.1 (A), C39.1
/Antenna/ANT_EXT_SEL: C39.2, JP1.1 (A), L2.1
/Antenna/ANT_PCB: AE2.1, R43.1, R44.2
/Antenna/ANT_PCB_SEL: JP1.3 (B), R42.2, R43.2
GND: AE1.2 (Shield), AE2.2, L2.2, R42.1, R44.1; also elsewhere on the board

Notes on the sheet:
Place matching circuits as close to the antenna as possible.
Antenna detection is not used.
Π-filter for tuning

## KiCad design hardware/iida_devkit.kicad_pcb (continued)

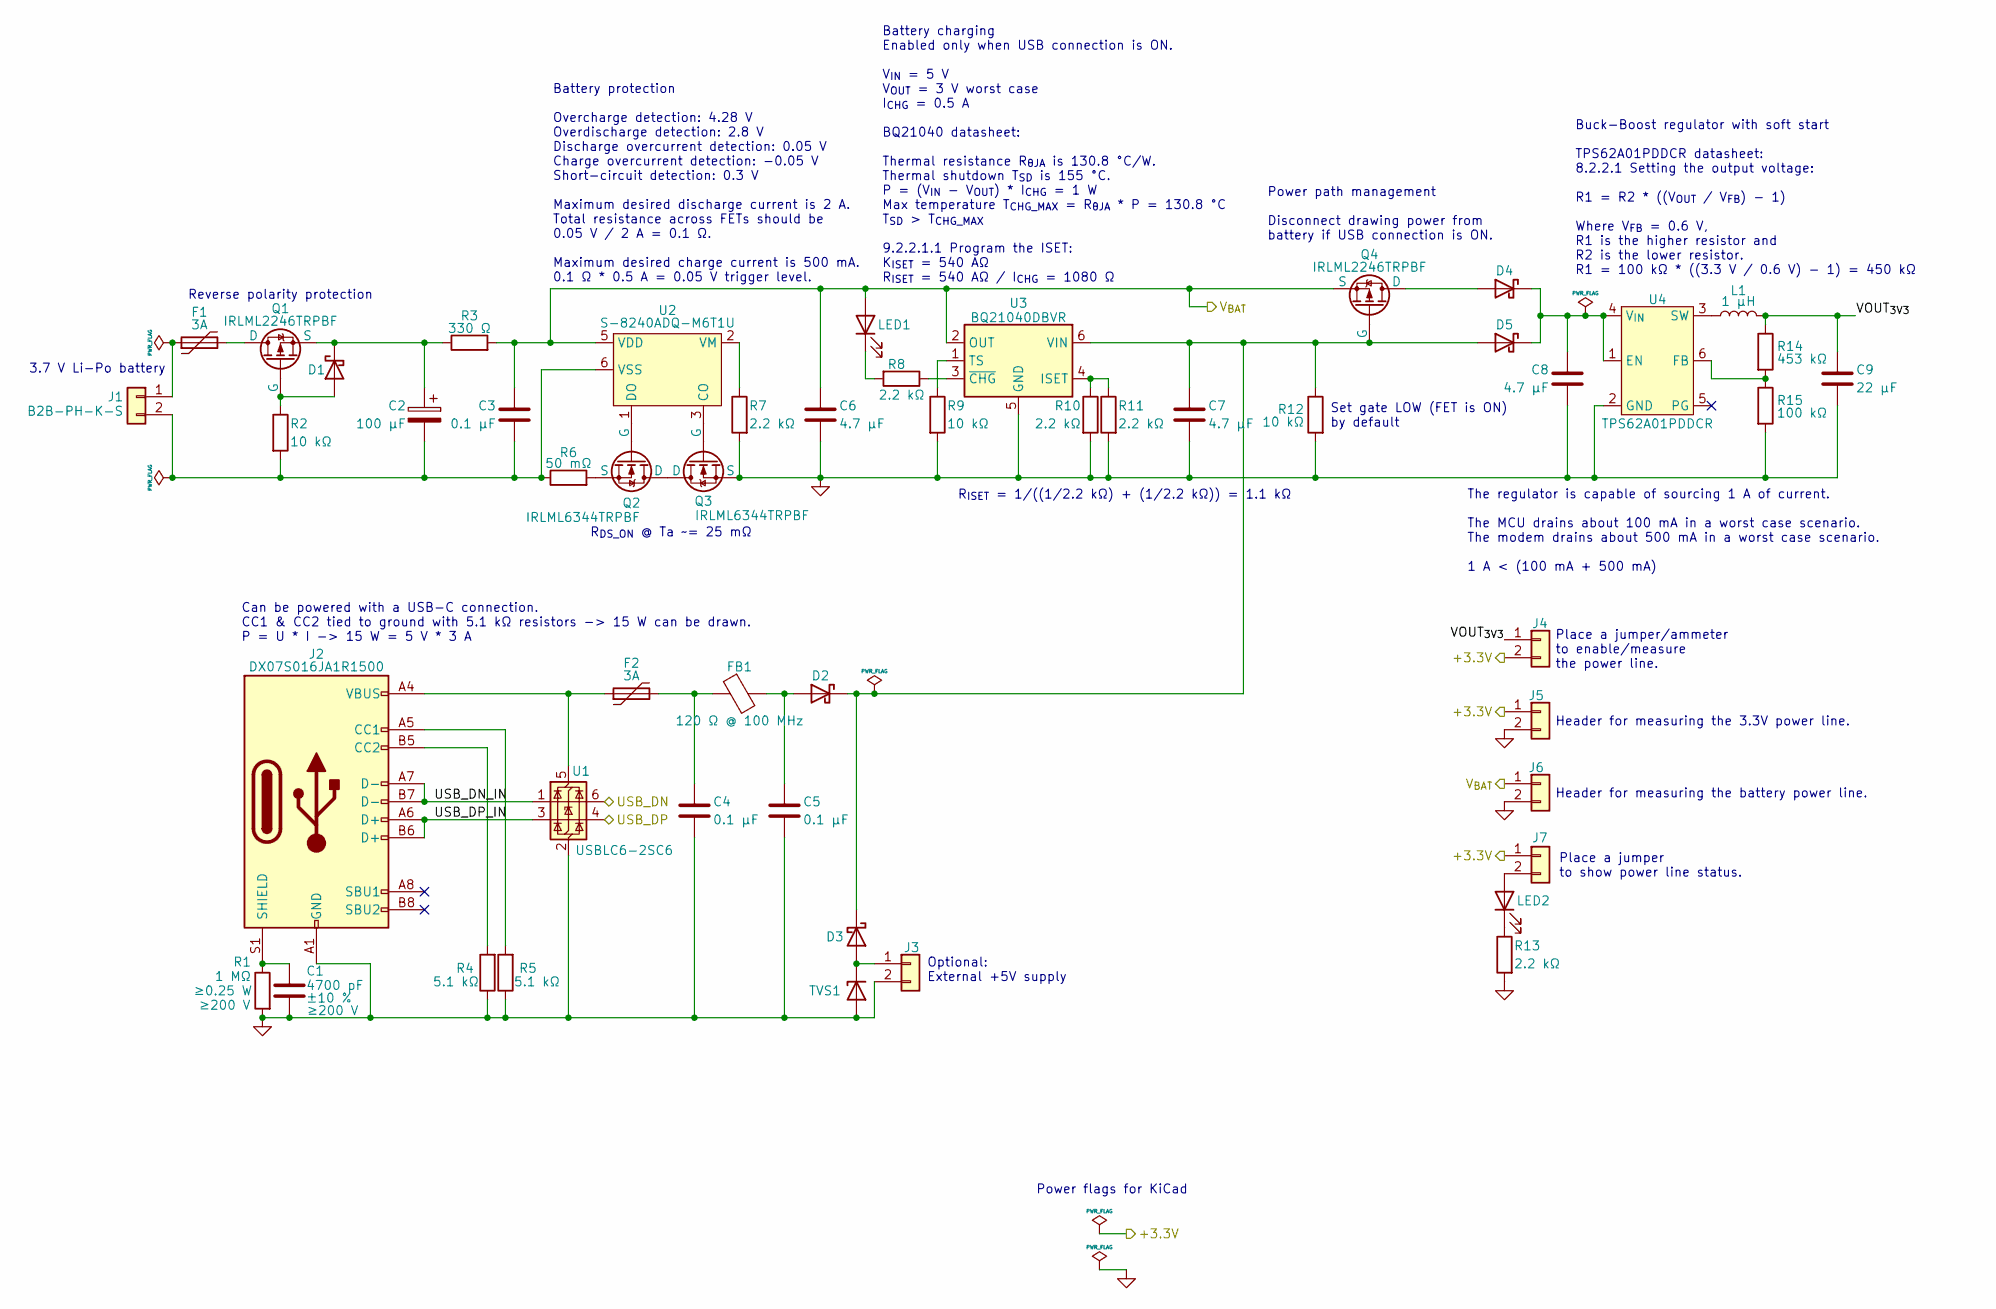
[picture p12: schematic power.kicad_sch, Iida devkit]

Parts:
C1: 4700 pF; C_0805_2012Metric_Pad1.18x1.45mm_HandSolder; Voltage rating ≥200 V; Tolerance ±10 %; Manufacturer Part Number 885342207009; Digi-Key Part Number 732-12165-1-ND
C2: 100 µF; CP_Elec_5x5.3; Manufacturer Part Number 865080142007; Digi-Key Part Number 732-8472-1-ND
C3, C4, C5: 0.1 µF; C_0603_1608Metric_Pad1.08x0.95mm_HandSolder; Manufacturer Part Number 885012206071; Digi-Key Part Number 732-7989-1-ND
C6, C7, C8: 4.7 µF; C_0805_2012Metric_Pad1.18x1.45mm_HandSolder; Manufacturer Part Number 885012107013; Digi-Key Part Number 732-7623-1-ND
C9: 22 µF; C_0805_2012Metric_Pad1.18x1.45mm_HandSolder; Manufacturer Part Number 885012107005; Digi-Key Part Number 732-7616-1-ND
D1, D2, D3, D4, D5: BAT60AE6327HTSA1; D_SOD-323_HandSoldering; Manufacturer Part Number BAT60AE6327HTSA1; Digi-Key Part Number BAT60AE6327HTSA1CT-ND
F1, F2: 3A; R_0805_2012Metric_Pad1.20x1.40mm_HandSolder; Manufacturer Part Number PTSLR08056V150; Digi-Key Part Number 283-PTSLR08056V150CT-ND
FB1: 120 Ω @ 100 MHz; R_0603_1608Metric_Pad0.98x0.95mm_HandSolder; Manufacturer Part Number BLM18KG121TN1D; Digi-Key Part Number 490-5254-1-ND
J1: B2B-PH-K-S; JST_PH_B2B-PH-K_1x02_P2.00mm_Vertical; Manufacturer Part Number B2B-PH-K-S; Digi-Key Part Number 455-1704-ND
J2: DX07S016JA1R1500; Manufacturer Part Number DX07S016JA1R1500; Digi-Key Part Number 670-DX07S016JA1R1500CT-ND
J3, J4, J5, J6, J7: PRPC001DAAN-RC; PinHeader_1x02_P2.54mm_Vertical; Manufacturer Part Number PRPC001DAAN-RC; Digi-Key Part Number S2011EC-01-ND
L1: 1 µH; L_1008_2520Metric_Pad1.43x2.20mm_HandSolder; Manufacturer Part Number DFE252012F-1R0M=P2; Digi-Key Part Number 490-13053-1-ND
LED1, LED2: 150141YS73100; LED_PLCC_2835_Handsoldering; Manufacturer Part Number 150141YS73100; Digi-Key Part Number 732-5004-1-ND
Q1, Q4: IRLML2246TRPBF; SC-59_Handsoldering; Manufacturer Part Number IRLML2246TRPBF; Digi-Key Part Number IRLML2246TRPBFCT-ND
Q2, Q3: IRLML6344TRPBF; SC-59_Handsoldering; Manufacturer Part Number IRLML6344TRPBF; Digi-Key Part Number IRLML6344TRPBFCT-ND
R1: 1 MΩ; R_1206_3216Metric_Pad1.30x1.75mm_HandSolder; Power rating ≥0.25 W; Working voltage ≥200 V; Manufacturer Part Number 560112132011; Digi-Key Part Number 732-560112132011CT-ND
R2, R9, R12: 10 kΩ; R_0603_1608Metric_Pad0.98x0.95mm_HandSolder; Manufacturer Part Number 560112116005; Digi-Key Part Number 732-560112116005CT-ND
R3: 330 Ω; R_0603_1608Metric_Pad0.98x0.95mm_HandSolder; Manufacturer Part Number 560112116020; Digi-Key Part Number 732-560112116020CT-ND
R4, R5: 5.1 kΩ; R_0805_2012Metric_Pad1.20x1.40mm_HandSolder; Manufacturer Part Number 560112120019; Digi-Key Part Number 732-560112120019CT-ND
R6: 50 mΩ; R_0603_1608Metric_Pad0.98x0.95mm_HandSolder; Manufacturer Part Number ERJ-3BWFR050V; Digi-Key Part Number P17472CT-ND
R7, R8, R10, R11, R13: 2.2 kΩ; R_0603_1608Metric_Pad0.98x0.95mm_HandSolder; Manufacturer Part Number 560112116098; Digi-Key Part Number 732-560112116098CT-ND
R14: 453 kΩ; R_0603_1608Metric_Pad0.98x0.95mm_HandSolder; Manufacturer Part Number SDR03EZPF4533; Digi-Key Part Number 846-SDR03EZPF4533CT-ND
R15: 100 kΩ; R_0603_1608Metric_Pad0.98x0.95mm_HandSolder; Manufacturer Part Number 560112116004; Digi-Key Part Number 732-560112116004CT-ND
TVS1: SMAJ6.0CA; D_SMA_Handsoldering; Manufacturer Part Number SMAJ6.0CA; Digi-Key Part Number 732-SMAJ6.0CACT-ND
U1: USBLC6-2SC6; SOT-23-6_Handsoldering; Manufacturer Part Number USBLC6-2SC6; Digi-Key Part Number 497-5235-1-ND
U2: S-8240ADQ-M6T1U; SOT-23-6_Handsoldering; Manufacturer Part Number S-8240ADQ-M6T1U; Digi-Key Part Number 1662-S-8240ADQ-M6T1UCT-ND
U3: BQ21040DBVR; SOT-23-6_Handsoldering; Manufacturer Part Number BQ21040DBVR; Digi-Key Part Number 296-47315-1-ND
U4: TPS62A01PDDCR; SOT-23-6_Handsoldering; Manufacturer Part Number TPS62A01PDDCR; Digi-Key Part Number 296-TPS62A01PDDCRCT-ND

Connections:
+3.3V: J4.2, J5.1, J7.1; also elsewhere on the board
+VBAT: C3.1, C6.1, J6.1, LED1.2 (A), Q4.3 (S), R3.2, U2.5 (VDD), U3.2 (OUT); also elsewhere on the board
/MCU/USB_DN: U1.6 (I/O1); also elsewhere on the board
/MCU/USB_DP: U1.4 (I/O2); also elsewhere on the board
/Power/USB_DN_IN: J2.A7 (D-), J2.B7 (D-), U1.1 (I/O1)
/Power/USB_DP_IN: J2.A6 (D+), J2.B6 (D+), U1.3 (I/O2)
/Power/VOUT_{3V3}: C9.1, J4.1, L1.2, R14.1
GND: C1.2, C4.2, C5.2, C6.2, C7.2, C8.2, C9.2, J2.A1 (GND), J2.A12 (GND), J2.B1 (GND), J2.B12 (GND), J3.2, J5.2, J6.2, Q3.3 (S), R1.2, R4.1, R5.1, R7.2, R9.2, R10.2, R11.2, R12.2, R13.2, R15.2, TVS1.2 (A), U1.2 (GND), U3.5 (GND), U4.2 (GND); also elsewhere on the board
unnamed: C4.1, F2.2, FB1.1
unnamed: D1.2 (A), Q1.2 (G), R2.1
unnamed: C2.1, D1.1 (K), Q1.3 (S), R3.1
unnamed: C5.1, D2.2 (A), FB1.2
unnamed: C7.1, D2.1 (K), D3.1 (K), D5.2 (A), Q4.2 (G), R12.1, U3.6 (VIN)
unnamed: D3.2 (A), J3.1, TVS1.1 (K)
unnamed: D4.2 (A), Q4.1 (D)
unnamed: C8.1, D4.1 (K), D5.1 (K), U4.1 (EN), U4.4 (V_{IN})
unnamed: F1.1, J1.1
unnamed: C2.2, C3.2, J1.2, R2.2, R6.1, U2.6 (VSS)
unnamed: J2.A5 (CC1), R5.2
unnamed: J2.B5 (CC2), R4.2
unnamed: C1.1, J2.S1 (SHIELD), R1.1
unnamed: J7.2, LED2.2 (A)
unnamed: LED1.1 (K), R8.2
unnamed: LED2.1 (K), R13.1
unnamed: F1.2, Q1.1 (D)
unnamed: Q2.1 (D), Q3.1 (D)
unnamed: Q2.2 (G), U2.1 (DO)
unnamed: Q2.3 (S), R6.2
unnamed: Q3.2 (G), U2.3 (CO)
unnamed: F2.1, J2.A4 (VBUS), J2.A9 (VBUS), J2.B4 (VBUS), J2.B9 (VBUS), U1.5 (VBUS)
unnamed: R7.1, U2.2 (VM)
unnamed: R10.1, R11.1, U3.4 (ISET)
unnamed: R9.1, U3.1 (TS)
unnamed: R8.1, U3.3 (~CHG)
unnamed: R14.2, R15.1, U4.6 (FB)
unnamed: L1.1, U4.3 (SW)

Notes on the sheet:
R_{ISET} = 1/((1/2.2 kΩ) + (1/2.2 kΩ)) = 1.1 kΩ
Can be powered with a USB-C connection. CC1 & CC2 tied to ground with 5.1 kΩ resistors -> 15 W can be drawn. P = U * I -> 15 W = 5 V * 3 A
R_{DS_ON} @ Ta ~= 25 mΩ
3.7 V Li-Po battery
Reverse polarity protection
Set gate LOW (FET is ON) by default
Buck-Boost regulator with soft start TPS62A01PDDCR datasheet: 8.2.2.1 Setting the output voltage: R1 = R2 * ((V_{OUT} / V_{FB}) - 1) Where V_{FB} = 0.6 V, R1 is the higher resistor and R2 is the lower resistor. R1 = 100 kΩ * ((3.3 V / 0.6 V) - 1) = 450 kΩ
Power path management Disconnect drawing power from battery if USB connection is ON.
Optional: External +5V supply
Power flags for KiCad
Place a jumper to show power line status.
Header for measuring the battery power line.
Battery protection Overcharge detection: 4.28 V Overdischarge detection: 2.8 V Discharge overcurrent detection: 0.05 V Charge overcurrent detection: -0.05 V Short-circuit detection: 0.3 V Maximum desired discharge current is 2 A. Total resistance across FETs should be 0.05 V / 2 A = 0.1 Ω. Maximum 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
Battery charging Enabled only when USB connection is ON. V_{IN} = 5 V V_{OUT} = 3 V worst case I_{CHG} = 0.5 A BQ21040 datasheet: Thermal resistance R_{θJA} is 130.8 °C/W. Thermal shutdown T_{SD} is 155 °C. P = (V_{IN} - V_{OUT}) * I_{CHG} = 1 W Max temperature T_{CHG_MAX} = R_{θJA} * P = 130.8 °C 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
Place a jumper/ammeter to enable/measure the power line.
Header for measuring the 3.3V power line.
The regulator is capable of sourcing 1 A of current. The MCU drains about 100 mA in a worst case scenario. The modem drains about 500 mA in a worst case scenario. 1 A < (100 mA + 500 mA)

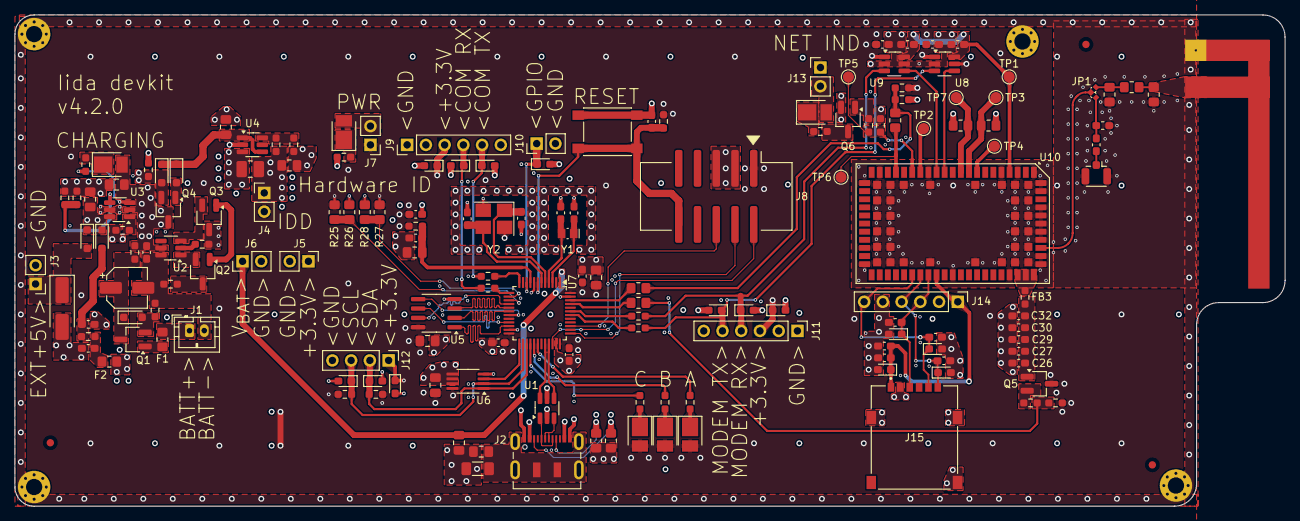
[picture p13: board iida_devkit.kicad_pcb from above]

Board: 4 copper layers, 172.2 x 66.6 mm, 167 parts (0 on the bottom side), 100 nets.

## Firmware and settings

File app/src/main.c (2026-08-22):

#include <zephyr/kernel.h>
#include <zephyr/app_version.h>
#include <zephyr/version.h>
#include <zephyr/autoconf.h>
#include <zephyr/device.h>
#include <zephyr/drivers/gpio.h>

#include "main.h"

#include <zephyr/logging/log.h>
LOG_MODULE_REGISTER(main, CONFIG_APP_LOG_LEVEL);

static const struct gpio_dt_spec ledA = GPIO_DT_SPEC_GET(DT_NODELABEL(led_a), gpios);

int main(void)
{
	LOG_INF("Iida devkit application: %s %s\n", APP_VERSION_STRING,
		STRINGIFY(APP_BUILD_VERSION));
	LOG_INF("Zephyr: %s\n", STRINGIFY(BUILD_VERSION));
	LOG_INF("Board: %s\n", CONFIG_BOARD_TARGET);
	LOG_INF("Built on %s @ %s\n", __DATE__, __TIME__);

	int err = 0;
	err = gpio_pin_configure_dt(&ledA, GPIO_OUTPUT_ACTIVE);
	if (err) {
		LOG_ERR("Error configuring LED A: %d", err);
		return err;
	}

	while (1) {
		err = gpio_pin_toggle_dt(&ledA);
		if (err) {
			LOG_ERR("Error toggling LED A: %d", err);
		}
		k_msleep(1000);
	}
}

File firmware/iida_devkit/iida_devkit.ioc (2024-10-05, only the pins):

Mcu.UserName=STM32L552CETx
PA11.GPIO_Label=USB_DN
PA11.Signal=USB_DM
PA12.Signal=USB_DP
PA2.GPIO_Label=COM_UART_TX
PA2.Signal=USART2_TX
PA3.GPIO_Label=COM_UART_RX
PA3.Signal=USART2_RX
PA4.GPIO_Label=HWID_1
PA4.Signal=GPIO_Input
PA5.GPIO_Label=HWID_2
PA5.Signal=GPIO_Input
PA6.GPIO_Label=EXT_FLASH_IO3
PA6.Signal=OCTOSPI1_IO3
PA7.GPIO_Label=EXT_FLASH_IO2
PA7.Signal=OCTOSPI1_IO2
PA8.GPIO_Label=LED_B
PA8.Signal=GPIO_Output
PA9.GPIO_Label=LED_A
PA9.Signal=GPIO_Output
PB0.GPIO_Label=EXT_FLASH_IO1
PB0.Signal=OCTOSPI1_IO1
PB1.GPIO_Label=EXT_FLASH_IO0
PB1.Signal=OCTOSPI1_IO0
PB10.GPIO_Label=EXT_FLASH_CLK
PB10.Signal=OCTOSPI1_CLK
PB11.GPIO_Label=EXT_FLASH_NCS
PB11.Signal=OCTOSPI1_NCS
PB12.GPIO_Label=TEMP_ALERT
PB12.Signal=GPXTI12
PB13.GPIO_Label=I2C_SCL
PB13.Signal=I2C2_SCL
PB14.GPIO_Label=I2C_SDA
PB14.Signal=I2C2_SDA
PB15.GPIO_Label=LED_C
PB15.Signal=GPIO_Output
PB6.GPIO_Label=MODEM_TX
PB6.Signal=USART1_TX
PB7.GPIO_Label=MODEM_RX
PB7.Signal=USART1_RX
PB8.GPIO_Label=MODEM_PWR_EN_N
PB8.Signal=GPIO_Output
PB9.GPIO_Label=MODEM_RESET_N
PB9.Signal=GPIO_Output

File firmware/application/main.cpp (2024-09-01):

#include "FreeRTOS.h"
#include "SEGGER_RTT.h"
#include "common.hpp"
#include "config.hpp"
#include "debug_print.h"
#include "gpio.hpp"
#include "pinmap.hpp"
#include "system.hpp"
#include "task.h"

extern "C" int debug_print_callback(char* debugMessage, unsigned int length) {
	unsigned avail = SEGGER_RTT_GetAvailWriteSpace(0);
	if (avail < length) {
		return DBG_PRINT_BUFFER_TOO_SMALL;
	}
	return SEGGER_RTT_Write(0, debugMessage, length);
}

void vApplicationStackOverflowHook(TaskHandle_t xTask, char* pcTaskName) {
	(void)xTask;
	DBG_PRINTF_ERROR("Task stack overflow: %s", pcTaskName);
	while (true) {}
}

/**
 * @brief Initialize system and peripherals.
 */
static void _Init() {
	SystemInit();
	SEGGER_RTT_Init();
}

static constexpr uint32_t LED_TASK_STACK_SIZE = 1'000UL;
static StackType_t        _ledTaskStack[LED_TASK_STACK_SIZE];
static StaticTask_t       _ledTaskBuffer;

static void _ledTask(void* arg) {
	(void)arg;
	Gpio led(
		LED_DBG_A,
		Gpio::Mode::OUTPUT,
		Gpio::Type::PUSH_PULL,
		Gpio::PullUp::PULL_UP,
		Gpio::Speed::LOW
	);
	led = 1;

	while (true) {
		if (led) {
			DBG_PRINTF_TRACE("Setting LED on");
		} else {
			DBG_PRINTF_TRACE("Setting LED off");
		}
		led = !led;
		vTaskDelay(pdMS_TO_TICKS(500));
	}
}

int main(void) {
	_Init();

	extern uint32_t const __header_start;
	AppHeader*            header =
		reinterpret_cast<AppHeader*>(const_cast<uint32_t*>(&__header_start));
	DBG_PRINTF_TRACE("Application start");
	DBG_PRINTF_TRACE("Timestamp: %s", header->metadata.timestamp);
	DBG_PRINTF_TRACE("Commit: %s", header->metadata.commit);
	DBG_PRINTF_TRACE("Toolchain: %s", header->metadata.toolchain);
	Sleep(msToTicks(500));

	xTaskCreateStatic(
		_ledTask,
		"LED",
		LED_TASK_STACK_SIZE,
		nullptr,
		tskIDLE_PRIORITY,
		_ledTaskStack,
		&_ledTaskBuffer
	);

	vTaskStartScheduler();

	while (true) {
		__NOP();
	}

	return 0;
}

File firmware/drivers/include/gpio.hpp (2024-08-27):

#pragma once

#include "error.hpp"
#include "stm32l552xx.h"

#include <cstdint>
#include <type_traits>

class Gpio {
public:
	enum class Mode : uint32_t {
		INPUT = 0UL,
		OUTPUT,
		ALTERNATE_FUNCTION,
		ANALOG
	};

	enum class Type : uint32_t {
		PUSH_PULL = 0UL,
		OPEN_DRAIN
	};

	enum class Speed : uint32_t {
		LOW = 0UL,
		MEDIUM,
		HIGH,
		VERY_HIGH
	};

	enum class PullUp : uint32_t {
		NONE = 0UL,
		PULL_UP,
		PULL_DOWN
	};

	enum class AlternateFunction : uint32_t {
		AF0 = 0UL,
		AF1,
		AF2,
		AF3,
		AF4,
		AF5,
		AF6,
		AF7,
		AF8,
		AF9,
		AF10,
		AF11,
		AF12,
		AF13,
		AF14,
		AF15
	};

	void SetMode(Mode mode) {
		_port->MODER &= ~(0b11 << (_pin * 2UL));
		uint32_t val = static_cast<uint32_t>(mode);
		_port->MODER |= (val << (_pin * 2UL));
	}

	void SetType(Type type) {
		_port->OTYPER &= ~(0b1 << _pin);
		uint32_t val = static_cast<uint32_t>(type);
		_port->OTYPER |= (val << _pin);
	}

	void SetSpeed(Speed speed) {
		_port->OSPEEDR &= ~(0b11 << (_pin * 2UL));
		uint32_t val = static_cast<uint32_t>(speed);
		_port->OSPEEDR |= (val << (_pin * 2UL));
	}

	void SetPullUp(PullUp pullup) {
		_port->PUPDR &= ~(0b11 << (_pin * 2UL));
		uint32_t val = static_cast<uint32_t>(pullup);
		_port->PUPDR |= (val << (_pin * 2UL));
	}

	void SetAlternateFunction(AlternateFunction af) {
		uint32_t idx = (_pin <= 7UL) ? 0UL : 1UL;
		_port->AFR[idx] &= ~(0b1111 << ((_pin % 8UL) * 4UL));
		uint32_t val = static_cast<uint32_t>(af);
		_port->AFR[idx] |= (val << ((_pin % 8UL) * 4UL));
	}

	void Write(bool on) {
		if (on) {
			_port->BSRR = (0b1 << _pin);
		} else {
			_port->BSRR = (0b1 << (_pin + 16UL));
		}
	}

	bool Read() {
		return _port->IDR & (0b1 << _pin);
	}

	Gpio& operator=(bool on) {
		Write(on);
		return *this;
	}

	Gpio& operator=(int on) {
		Write(on == 1 ? true : false);
		return *this;
	}

	Gpio& operator=(Gpio& other) {
		// Prevent self-assigment
		if (this == &other) {
			return *this;
		}
		Write(other.Read());
		return *this;
	}

	bool operator==(bool on) {
		return Read() == on;
	}

	operator bool() {
		return Read();
	}

	Gpio(
		GPIO_TypeDef* const port,
		uint32_t            pin,
		Mode                mode   = Mode::ANALOG,
		Type                type   = Type::PUSH_PULL,
		PullUp              pullup = PullUp::NONE,
		Speed               speed  = Speed::LOW,
		AlternateFunction   af     = AlternateFunction::AF0
	) {
		switch (reinterpret_cast<uint32_t>(port)) {
			case GPIOA_BASE:
				RCC->AHB2ENR |= RCC_AHB2ENR_GPIOAEN;
				break;
			case GPIOB_BASE:
				RCC->AHB2ENR |= RCC_AHB2ENR_GPIOBEN;
				break;
			case GPIOC_BASE:
				RCC->AHB2ENR |= RCC_AHB2ENR_GPIOCEN;
				break;
			case GPIOD_BASE:
				RCC->AHB2ENR |= RCC_AHB2ENR_GPIODEN;
				break;
			case GPIOE_BASE:
				RCC->AHB2ENR |= RCC_AHB2ENR_GPIOEEN;
				break;
			case GPIOF_BASE:
				RCC->AHB2ENR |= RCC_AHB2ENR_GPIOFEN;
				break;
			case GPIOG_BASE:
				RCC->AHB2ENR |= RCC_AHB2ENR_GPIOGEN;
				break;
			case GPIOH_BASE:
				RCC->AHB2ENR |= RCC_AHB2ENR_GPIOHEN;
				break;
			default:
				PANIC(
					"Bad GPIO port: 0x%08X", reinterpret_cast<uint32_t>(port)
				);
		}
		if (pin > _PIN_MAX) {
			PANIC("Bad GPIO pin: %u", pin);
		}
		_port = port;
		_pin  = pin;
		SetMode(mode);
		SetType(type);
		SetPullUp(pullup);
		SetSpeed(speed);
		SetAlternateFunction(af);
	}

	~Gpio() {
		SetMode(Mode::ANALOG);
		SetType(Type::PUSH_PULL);
		SetPullUp(PullUp::NONE);
		SetSpeed(Speed::LOW);
		SetAlternateFunction(AlternateFunction::AF0);
	}

private:
	static constexpr uint32_t _PIN_MAX = 15UL;
	GPIO_TypeDef*             _port    = nullptr;
	uint32_t                  _pin     = _PIN_MAX + 1;
};

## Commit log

2024-06-08 Initial commit with cleaned up history
    [iida_devkit.kicad_pcb, iida_devkit.kicad_sch, modem.kicad_sch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]
2024-06-09 Add stubs to fix builds
    [gpio.hpp, main.cpp, system.cpp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]
2024-07-01 Fix bootloader main codestyle
    [main.cpp]
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2024-07-04 Fix stuff based on testing
    [main.c, system.cpp]
2024-07-04 Apply fixes to PTSW based on testing
    [iida_devkit.ioc, main.c]
2024-07-04 Fix bootloader based on testing
    [main.cpp, system.cpp, system.hpp]
2024-07-06 Fix UART based on testing
    [iida_devkit.ioc, main.cpp, pinmap.hpp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]
2024-07-06 Bugfixes and YModem support
    - Increase stack size to fix crash when using Segger RTT stuff
    - Start adding YModem support for bootloader
    [main.cpp, system.cpp, system.hpp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]
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2024-07-10 Fix XMODEM receive packet return type
    [xmodem.cpp]
2024-07-10 Develop flash support further, erase doesn't work
    [main.cpp, system.cpp]
2024-07-11 Fix issues with Flash and use it for self tests
    [main.cpp, system.cpp]
2024-07-12 Rework app header implementation
    [main.cpp]
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2024-09-06 Start working on hw v4.0.0
    [iida_devkit.kicad_sch, mcu.kicad_sch, modem.kicad_sch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]
2024-09-07 HW: Continue developing
    [iida_devkit.kicad_sch, mcu.kicad_sch, modem.kicad_sch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]
2024-09-08 HW: Develop further
    [iida_devkit.kicad_sch, mcu.kicad_sch, modem.kicad_sch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]
2024-09-09 Update 4 layer stackup project rules
    [iida_devkit.kicad_pcb]
2024-09-09 HW: Layout power section
    [iida_devkit.kicad_pcb, power.kicad_sch]
2024-09-09 HW: Initial MCU layout
    [iida_devkit.kicad_pcb, mcu.kicad_sch]
2024-09-09 HW: Layout SIM section
    [iida_devkit.kicad_pcb, sim.kicad_sch]
2024-09-09 HW: Layout modem
    [iida_devkit.kicad_pcb, modem.kicad_sch]
2024-09-09 HW: Finish laying out sections
    [iida_devkit.kicad_pcb, mcu.kicad_sch]
2024-09-10 HW: Make sections more compact
    [iida_devkit.kicad_pcb, mcu.kicad_sch, modem.kicad_sch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]
2024-09-10 HW: Rework power section
    [iida_devkit.kicad_pcb, iida_devkit.kicad_sch, mcu.kicad_sch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]
2024-09-10 HW: Replace SMA with U.FL
    [iida_devkit.kicad_pcb, modem.kicad_sch]
2024-09-10 HW: Ready for routing
    [iida_devkit.kicad_pcb, modem.kicad_sch]
2024-09-10 HW: Route power
    [iida_devkit.kicad_pcb]
2024-09-10 HW: Initial layout and routing done
    [iida_devkit.kicad_pcb, iida_devkit.kicad_sch, mcu.kicad_sch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]
2024-09-10 HW: Stitch layers together
    [iida_devkit.kicad_pcb]
2024-09-11 HW: Fix via placement
    [iida_devkit.kicad_pcb]
2024-09-11 HW: Cleanup
    [iida_devkit.kicad_pcb]
2024-09-11 HW: Add teardrops
    [iida_devkit.kicad_pcb]
2024-09-11 HW: Place components on top layer only
    [iida_devkit.kicad_pcb]
2024-09-20 HW: Update schematic
    [iida_devkit.kicad_sch, mcu.kicad_sch, modem.kicad_sch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]
2024-09-20 HW: Start PCB over with new stackup
    [iida_devkit.kicad_pcb]
2024-09-20 HW: Add PCB antenna option
    [antenna.kicad_sch, iida_devkit.kicad_sch, modem.kicad_sch]
2024-09-20 HW: Add layout guidelines/reminders to schematic
    [antenna.kicad_sch, iida_devkit.kicad_sch]
2024-09-20 HW: Cleanup schematic
    [antenna.kicad_sch, modem.kicad_sch, sim.kicad_sch]
2024-09-20 HW: Layout power
    [iida_devkit.kicad_pcb]
2024-09-21 HW: Fix PCB antenna
    [antenna.kicad_sch, iida_devkit.kicad_pcb]
2024-09-21 HW: Add series termination to UART lines
    [antenna.kicad_sch, iida_devkit.kicad_pcb, mcu.kicad_sch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]
2024-09-21 HW: Layout antenna
    [antenna.kicad_sch, iida_devkit.kicad_pcb]
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2024-09-21 HW: Layout Modem and SIM
    [iida_devkit.kicad_pcb, modem.kicad_sch]
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2024-09-21 HW: Stitch grounds together
    [iida_devkit.kicad_pcb, iida_devkit.kicad_sch]
2024-09-21 HW: Fix HWID R15
    [iida_devkit.kicad_pcb, mcu.kicad_sch]
2024-09-22 HW: Change USB connector, add TVS to headers, fix layout
    [antenna.kicad_sch, iida_devkit.kicad_pcb, mcu.kicad_sch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]
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2024-09-22 HW: Update date on sheets
    [antenna.kicad_sch, iida_devkit.kicad_pcb, iida_devkit.kicad_sch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]
2024-09-22 HW: Update 0hm choice
    [antenna.kicad_sch, iida_devkit.kicad_pcb]
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2024-09-22 HW: Fix BOM
    [modem.kicad_sch]
2024-09-22 HW: TC2030 -> TC2050
    [antenna.kicad_sch, iida_devkit.kicad_pcb, mcu.kicad_sch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]
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2024-09-22 HW: Replace chinese NPN BJT
    [iida_devkit.kicad_pcb, modem.kicad_sch]
2024-09-25 HW: Connect +BATT to MCU
    [antenna.kicad_sch, iida_devkit.kicad_pcb, iida_devkit.kicad_sch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]
2024-09-26 HW: Improve thermals, silkscreen and schematic
    [iida_devkit.kicad_pcb, iida_devkit.kicad_sch, mcu.kicad_sch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]
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2024-09-28 HW: Update VBAT, schema and layout
    [antenna.kicad_sch, iida_devkit.kicad_pcb, iida_devkit.kicad_sch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]
2024-09-28 HW: Start adding Li-Po support
    [antenna.kicad_sch, iida_devkit.kicad_sch, mcu.kicad_sch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]
2024-10-05 HW: Fix 5.1K USB resistors
    [power.kicad_sch]
2024-10-05 HW: Replace STM QFN with QFP
    [antenna.kicad_sch, mcu.kicad_sch, modem.kicad_sch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]
2024-10-05 HW: Replace TC2050 wiht 10-pin connector
    [iida_devkit.kicad_sch, mcu.kicad_sch, power.kicad_sch]
2024-10-05 HW: Update components to be hand solderable
    [antenna.kicad_sch, mcu.kicad_sch, modem.kicad_sch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]
2024-10-05 HW: Update components, change footprints to handsolder versions, finish power
    [antenna.kicad_sch, mcu.kicad_sch, modem.kicad_sch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]
2024-10-06 HW: Add fuses to USB and battery
    [power.kicad_sch]
2024-10-06 HW: Add formula for FB resistors of regulator
    [power.kicad_sch]
2024-10-06 HW: Add battery protection
    [antenna.kicad_sch, mcu.kicad_sch, modem.kicad_sch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]
2024-10-06 HW: Resize modem power fet gate resistor
    [modem.kicad_sch]
2024-10-06 HW: Replace 0402 with 0603 or bigger
    [antenna.kicad_sch, mcu.kicad_sch, modem.kicad_sch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]
2024-10-06 HW: Start layout all over again
    [iida_devkit.kicad_pcb]
2024-10-06 HW: Fix 3D models for components
    [iida_devkit.kicad_pcb]
2024-10-06 HW: Layout antenna section
    [iida_devkit.kicad_pcb]
2024-10-06 HW: Layout modem and SIM together
    [iida_devkit.kicad_pcb]
2024-10-07 HW: Layout MCU section
    [iida_devkit.kicad_pcb, mcu.kicad_sch, power.kicad_sch]
2024-10-08 HW: Refine modem layout
    [iida_devkit.kicad_pcb]
2024-10-08 HW: Route sections together
    [iida_devkit.kicad_pcb]
2024-10-09 HW: Connect nets and fill layers
    [iida_devkit.kicad_pcb]
2024-10-09 HW: Fix programming header and layout
    [iida_devkit.kicad_pcb, mcu.kicad_sch]
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2024-10-10 HW: Add bulk cap to VBAT
    [antenna.kicad_sch, iida_devkit.kicad_pcb, mcu.kicad_sch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]
2024-10-10 HW: Document current consumption to power sheet
    [power.kicad_sch]
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2024-10-10 HW: Fix teardrops
    [iida_devkit.kicad_pcb]
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2024-10-11 HW: Add project description to main schema sheet
    [iida_devkit.kicad_sch]
2024-10-11 HW: Replace USB-C connector
    [iida_devkit.kicad_pcb, power.kicad_sch]
2024-10-11 HW: Fix components
    [antenna.kicad_sch, iida_devkit.kicad_pcb, mcu.kicad_sch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]
2024-10-11 HW: Refine schema text
    [iida_devkit.kicad_sch, power.kicad_sch]
2024-10-12 HW: Refine schema and layout
    [antenna.kicad_sch, iida_devkit.kicad_pcb, power.kicad_sch]
2024-10-12 HW: Refine schema and layout based on review
    [antenna.kicad_sch, iida_devkit.kicad_pcb, mcu.kicad_sch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]
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2024-10-13 HW: Fix antenna selection stub
    [antenna.kicad_sch, iida_devkit.kicad_pcb]
2024-10-13 HW: Fix power dissipation calculation in power sheet
    [power.kicad_sch]
2024-10-13 HW: Improve external antenna placement
    [iida_devkit.kicad_pcb]
2024-10-13 HW: Improve power delivery
    [iida_devkit.kicad_pcb]
2024-10-14 HW: Fix component assignments
    [iida_devkit.kicad_pcb, mcu.kicad_sch, power.kicad_sch]
2024-10-14 HW: Add via fence and stitch planes
    [iida_devkit.kicad_pcb, power.kicad_sch]
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2024-10-15 HW: Fix C1 footprint
    [iida_devkit.kicad_pcb, power.kicad_sch]
2024-10-15 HW: Fix footprints
    [iida_devkit.kicad_pcb, mcu.kicad_sch, power.kicad_sch]
2024-10-15 HW: Fix layout
    [iida_devkit.kicad_pcb, power.kicad_sch]
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2026-07-06 Fix EEPROM dts and clean up main
    [main.c]
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
